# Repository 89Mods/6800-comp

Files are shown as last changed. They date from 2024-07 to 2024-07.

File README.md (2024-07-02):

# 6800-comp

Computer with a 6800 (or 6809) CPU. See [here](https://tholin.dev/6800/) for more information.

`Emu` contains an emulation of the computer (6800 mode only) written in C++.

`Hardware` contains the KiCad projects for all the boards.

`Kernal` contains the kernal sources that go on the EPROM.

`Software` contains all kinds of software I’ve written for this computer.

The [ASL Assembler](https://github.com/Macroassembler-AS/asl-releases) is required to build all code in this project.

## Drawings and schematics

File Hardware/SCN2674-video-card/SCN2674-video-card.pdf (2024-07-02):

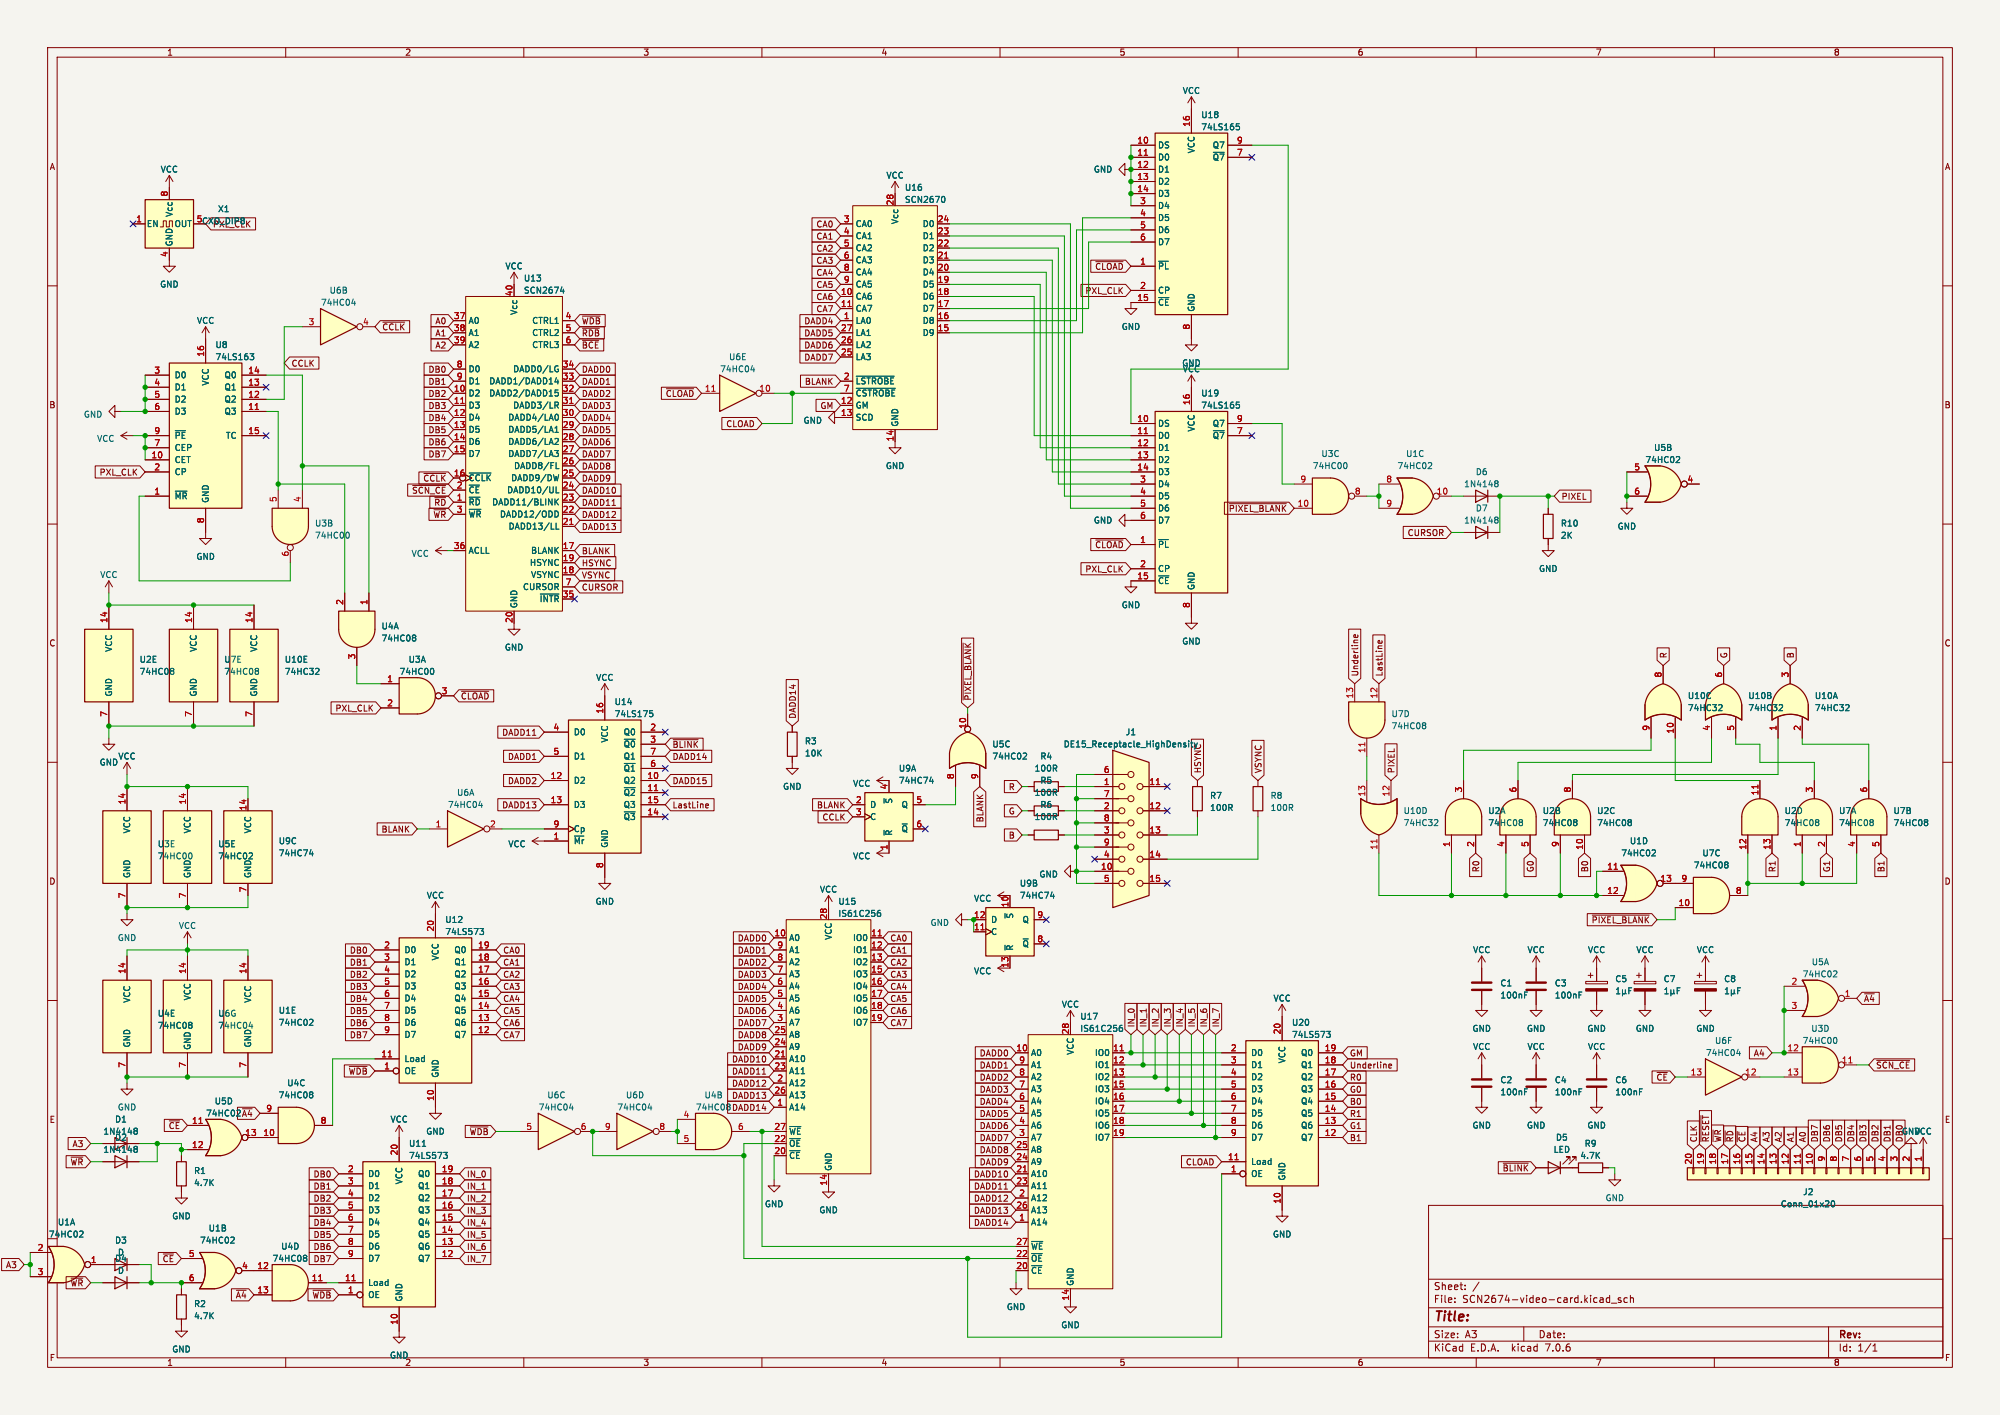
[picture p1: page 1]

VCC GND GND VCC

Id: 1/1 Title: File: SCN2674-video-card.kicad_sch Sheet: /

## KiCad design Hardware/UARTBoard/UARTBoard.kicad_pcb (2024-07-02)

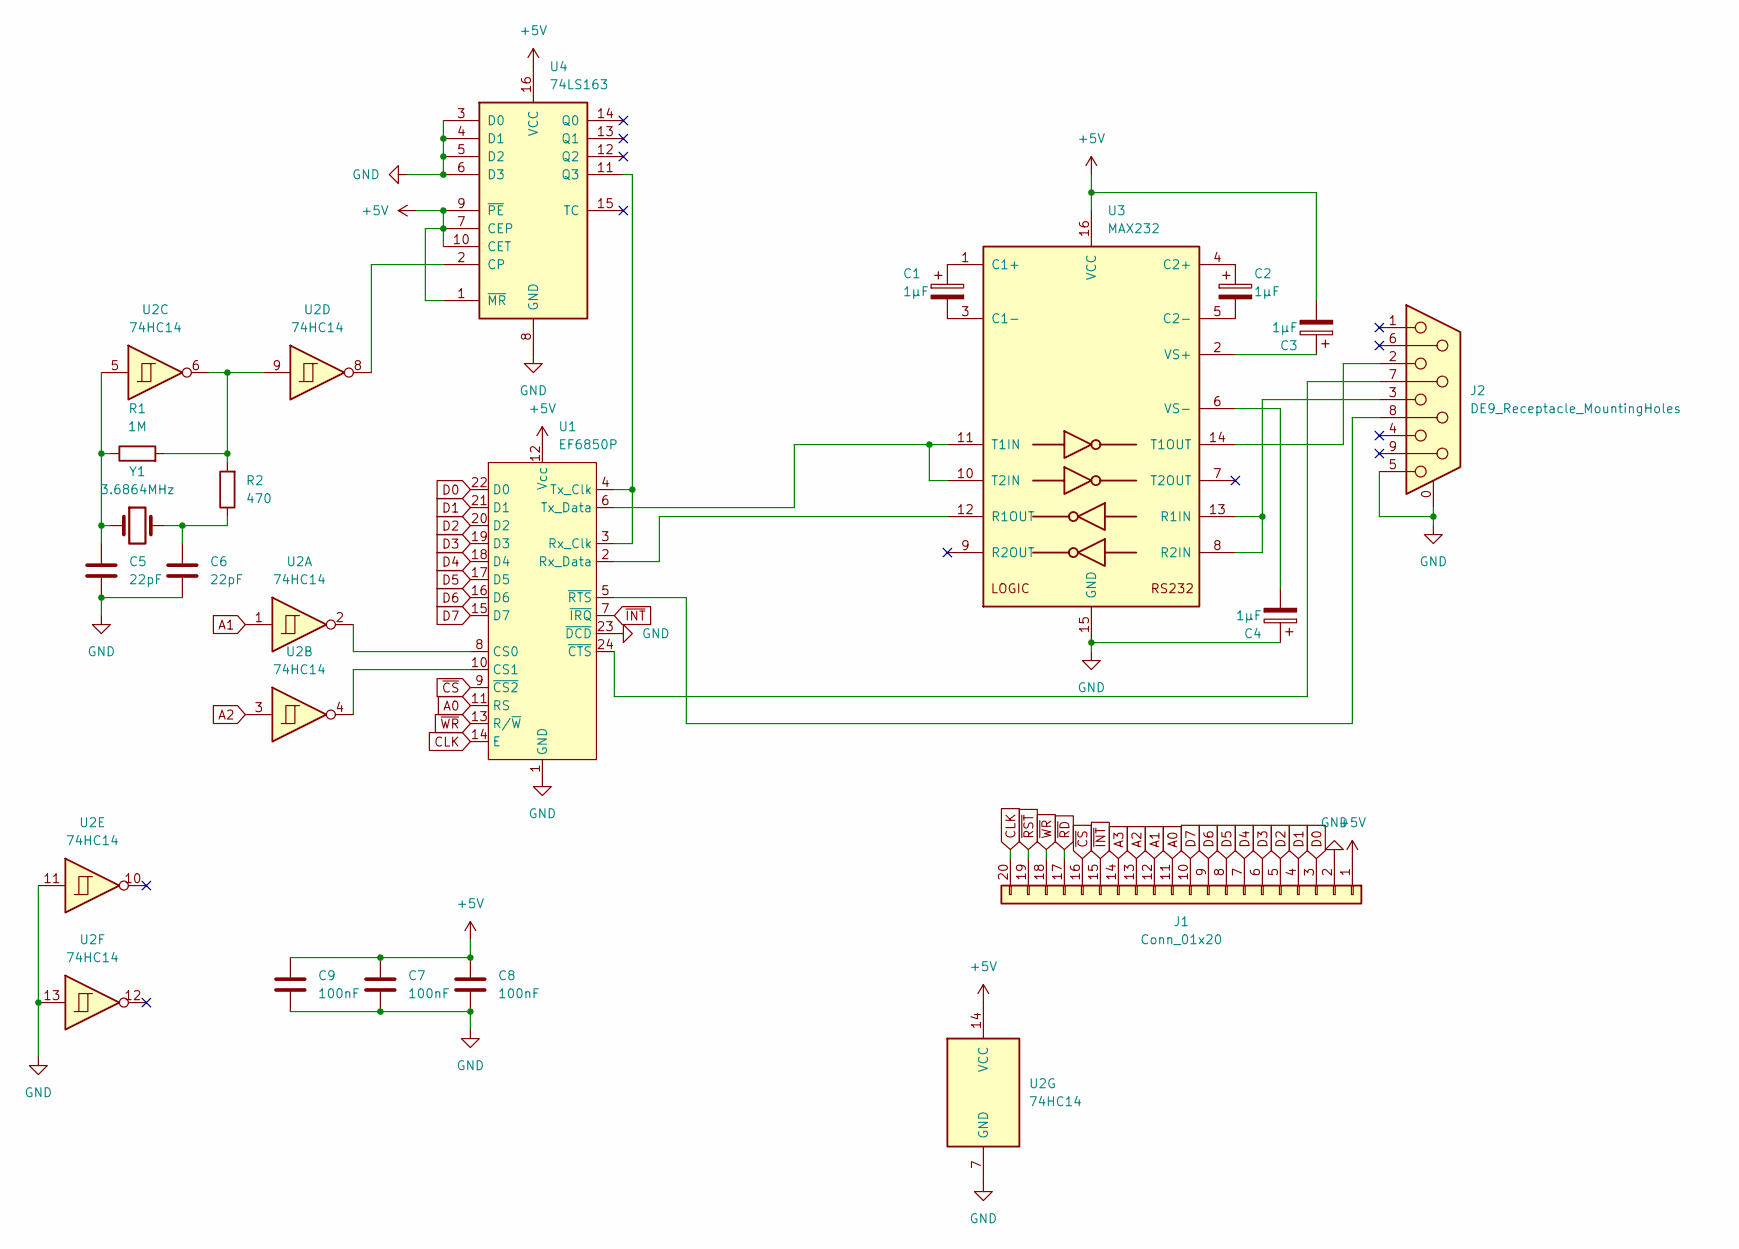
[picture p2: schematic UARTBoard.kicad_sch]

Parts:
C1, C2, C3, C4: 1µF; CP_Radial_D4.0mm_P2.00mm
C5, C6: 22pF; C_Disc_D3.0mm_W1.6mm_P2.50mm
C7, C8, C9: 100nF; C_Disc_D3.0mm_W1.6mm_P2.50mm
J1: Conn_01x20; PinHeader_1x20_P2.54mm_Vertical
J2: DE9_Receptacle_MountingHoles; DSUB-9_Female_Horizontal_P2.77x2.84mm_EdgePinOffset4.94mm_H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
R1: 1M; R_Axial_DIN0204_L3.6mm_D1.6mm_P7.62mm_Horizontal
R2: 470; R_Axial_DIN0204_L3.6mm_D1.6mm_P7.62mm_Horizontal
U1: EF6850P; DIP-24_W15.24mm
U2: 74HC14; DIP-14_W7.62mm
U3: MAX232; DIP-16_W7.62mm
U4: 74LS163; DIP-16_W7.62mm
Y1: 3.6864MHz; Crystal_HC18-U_Vertical

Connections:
+5V: C3.2, C7.1, C8.1, C9.1, J1.1, U1.12 (Vcc), U2.14 (VCC), U3.16 (VCC), U4.1 (~MR), U4.7 (CEP), U4.9 (~PE), U4.10 (CET), U4.16 (VCC)
A0: J1.11, U1.11 (RS)
A1: J1.12, U2.1
A2: J1.13, U2.3
A3: J1.14
CLK: J1.20, U1.14 (E)
D0: J1.3, U1.22 (D0)
D1: J1.4, U1.21 (D1)
D2: J1.5, U1.20 (D2)
D3: J1.6, U1.19 (D3)
D4: J1.7, U1.18 (D4)
D5: J1.8, U1.17 (D5)
D6: J1.9, U1.16 (D6)
D7: J1.10, U1.15 (D7)
GND: C4.1, C5.2, C6.2, C7.2, C8.2, C9.2, J1.2, J2.0 (PAD), J2.5, U1.1 (GND), U1.23 (~DCD), U2.7 (GND), U2.11, U2.13, U3.15 (GND), U4.3 (D0), U4.4 (D1), U4.5 (D2), U4.6 (D3), U4.8 (GND)
unnamed: C5.1, R1.1, U2.5, Y1.1
unnamed: C6.1, R2.1, Y1.2
unnamed: R1.2, R2.2, U2.6, U2.9
unnamed: U1.8 (CS0), U2.2
unnamed: U1.10 (CS1), U2.4
unnamed: U1.3 (Rx_Clk), U1.4 (Tx_Clk), U4.11 (Q3)
unnamed: U1.2 (Rx_Data), U3.12 (R1OUT)
unnamed: U1.6 (Tx_Data), U3.10 (T2IN), U3.11 (T1IN)
unnamed: J2.7, U1.24 (~CTS)
unnamed: J2.8, U1.5 (~RTS)
unnamed: C1.1, U3.1 (C1+)
unnamed: C1.2, U3.3 (C1-)
unnamed: C2.1, U3.4 (C2+)
unnamed: C2.2, U3.5 (C2-)
unnamed: J2.3, U3.8 (R2IN), U3.13 (R1IN)
unnamed: J2.2, U3.14 (T1OUT)
unnamed: C3.1, U3.2 (VS+)
unnamed: C4.2, U3.6 (VS-)
unnamed: U2.8, U4.2 (CP)
~CS: J1.16, U1.9 (~CS2)
~INT: J1.15, U1.7 (~IRQ)
~RD: J1.17
~RST: J1.19
~WR: J1.18, U1.13 (R/~W)

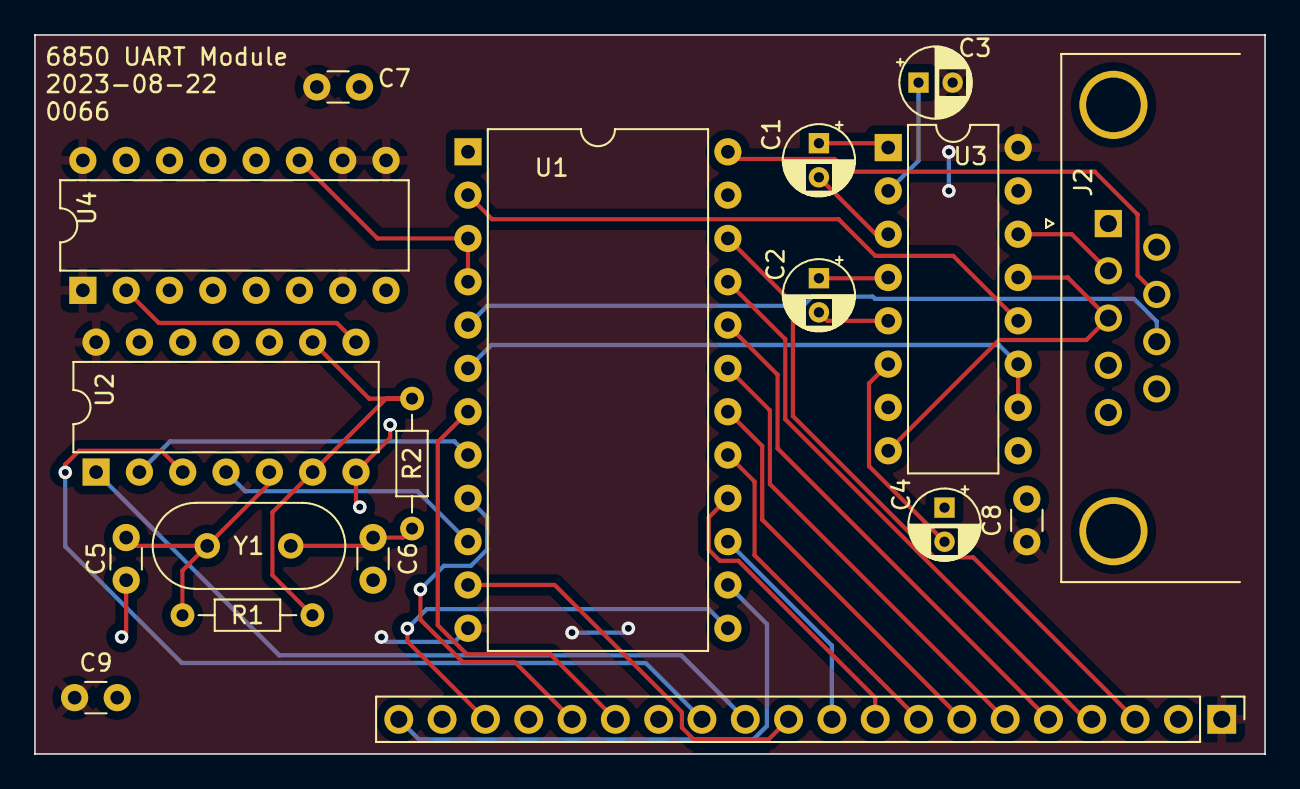
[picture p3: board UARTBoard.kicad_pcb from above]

Board: 2 copper layers, 72.1 x 42.2 mm, 18 parts (0 on the bottom side), 36 nets.

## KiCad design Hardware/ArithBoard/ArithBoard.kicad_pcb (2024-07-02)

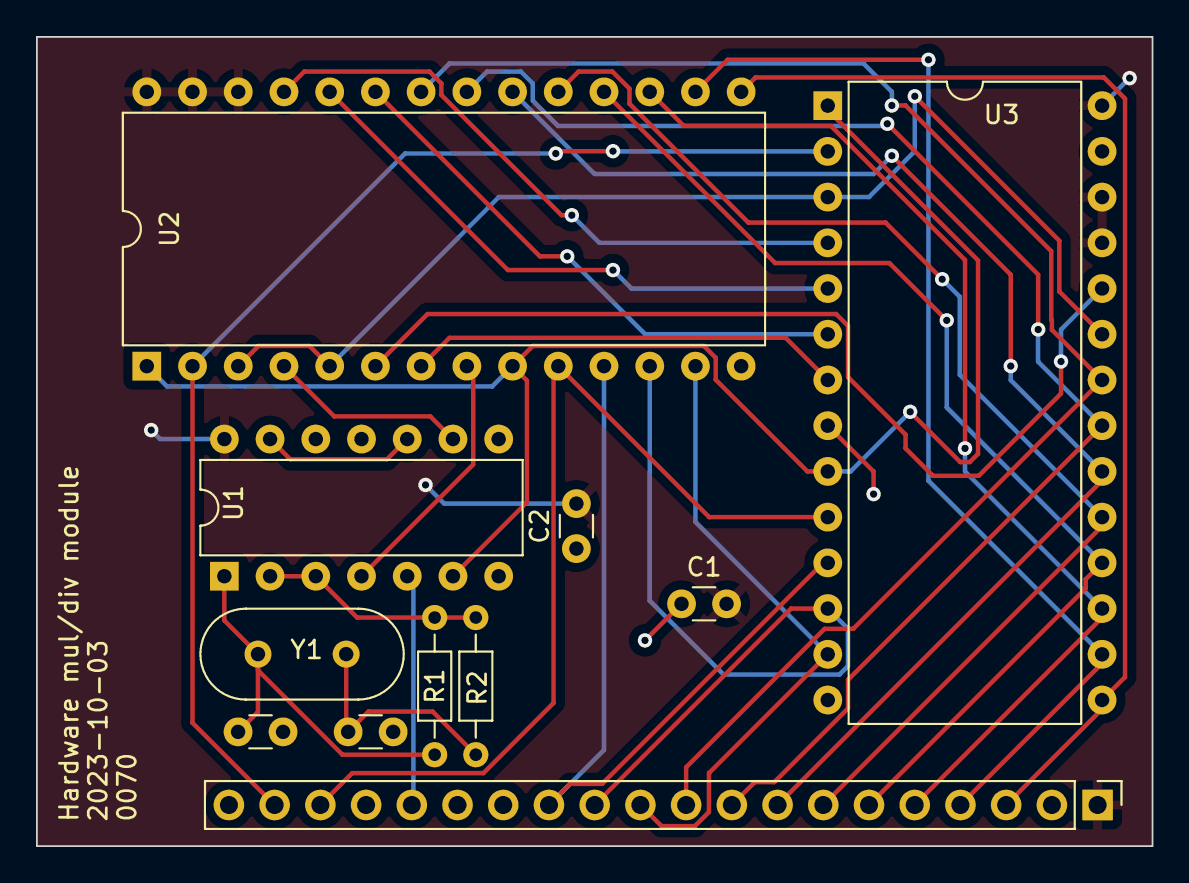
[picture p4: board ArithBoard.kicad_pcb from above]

Board: 2 copper layers, 62.0 x 45.0 mm, 11 parts (0 on the bottom side), 29 nets.

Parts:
C1, C2: 100nF; C_Disc_D3.0mm_W1.6mm_P2.50mm
C3, C4: 22pF; C_Disc_D3.0mm_W1.6mm_P2.50mm
J1: Conn_01x20; PinHeader_1x20_P2.54mm_Vertical
R1: 1M; R_Axial_DIN0204_L3.6mm_D1.6mm_P7.62mm_Horizontal
R2: 470; R_Axial_DIN0204_L3.6mm_D1.6mm_P7.62mm_Horizontal
U1: 74HC14; DIP-14_W7.62mm
U2, U3: CDP1855; DIP-28_W15.24mm
Y1: 3.6864MHz; Crystal_HC18-U_Vertical

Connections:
+5V: C1.2, C2.2, J1.1, U1.14 (VCC), U2.26 (CN1), U2.27 (CN0), U2.28 (Vdd), U3.25 (~CI), U3.26 (CN1), U3.28 (Vdd)
A0: J1.11, U2.13 (RA0), U3.13 (RA0)
A1: J1.12, U2.12 (RA1), U3.12 (RA1)
A2: J1.13, U2.11 (RA2), U3.11 (RA2)
CS: U1.6, U2.1 (CE), U2.9 (STB), U3.1 (CE), U3.9 (STB)
D0: J1.3, U2.15 (BUS0), U3.15 (BUS0)
D1: J1.4, U2.16 (BUS1), U3.16 (BUS1)
D2: J1.5, U2.17 (BUS2), U3.17 (BUS2)
D3: J1.6, U2.18 (BUS3), U3.18 (BUS3)
D4: J1.7, U2.19 (BUS4), U3.19 (BUS4)
D5: J1.8, U2.20 (BUS5), U3.20 (BUS5)
D6: J1.9, U2.21 (BUS6), U3.21 (BUS6)
D7: J1.10, U2.22 (BUS7), U3.22 (BUS7)
GND: C1.1, C2.1, C3.2, C4.2, J1.2, U1.7 (GND), U1.11, U2.14 (GND), U3.8 (CLK), U3.14 (GND), U3.27 (CN0)
unnamed: C3.1, R1.1, U1.1, Y1.1
unnamed: C4.1, R2.1, Y1.2
unnamed: R1.2, R2.2, U1.2, U1.3
unnamed: U1.10, U1.13
unnamed: U1.4, U2.8 (CLK)
unnamed: U2.3 (CTL), U2.5 (Y_L), U3.3 (CTL), U3.23 (Z_R)
unnamed: U2.24 (Y_R), U3.5 (Y_L)
unnamed: U2.6 (Z_L), U3.24 (Y_R)
unnamed: U2.23 (Z_R), U3.6 (Z_L)
unnamed: U2.25 (~CI), U3.4 (~CO/~OF)
unnamed: U1.9, U2.4 (~CO/~OF)
unnamed: U2.7 (~SHIFT), U3.7 (~SHIFT)
~CS: J1.16, U1.5
~RESET: J1.19, U2.2 (~CLEAR), U3.2 (~CLEAR)
~WR: J1.18, U2.10 (RD/~WE), U3.10 (RD/~WE)

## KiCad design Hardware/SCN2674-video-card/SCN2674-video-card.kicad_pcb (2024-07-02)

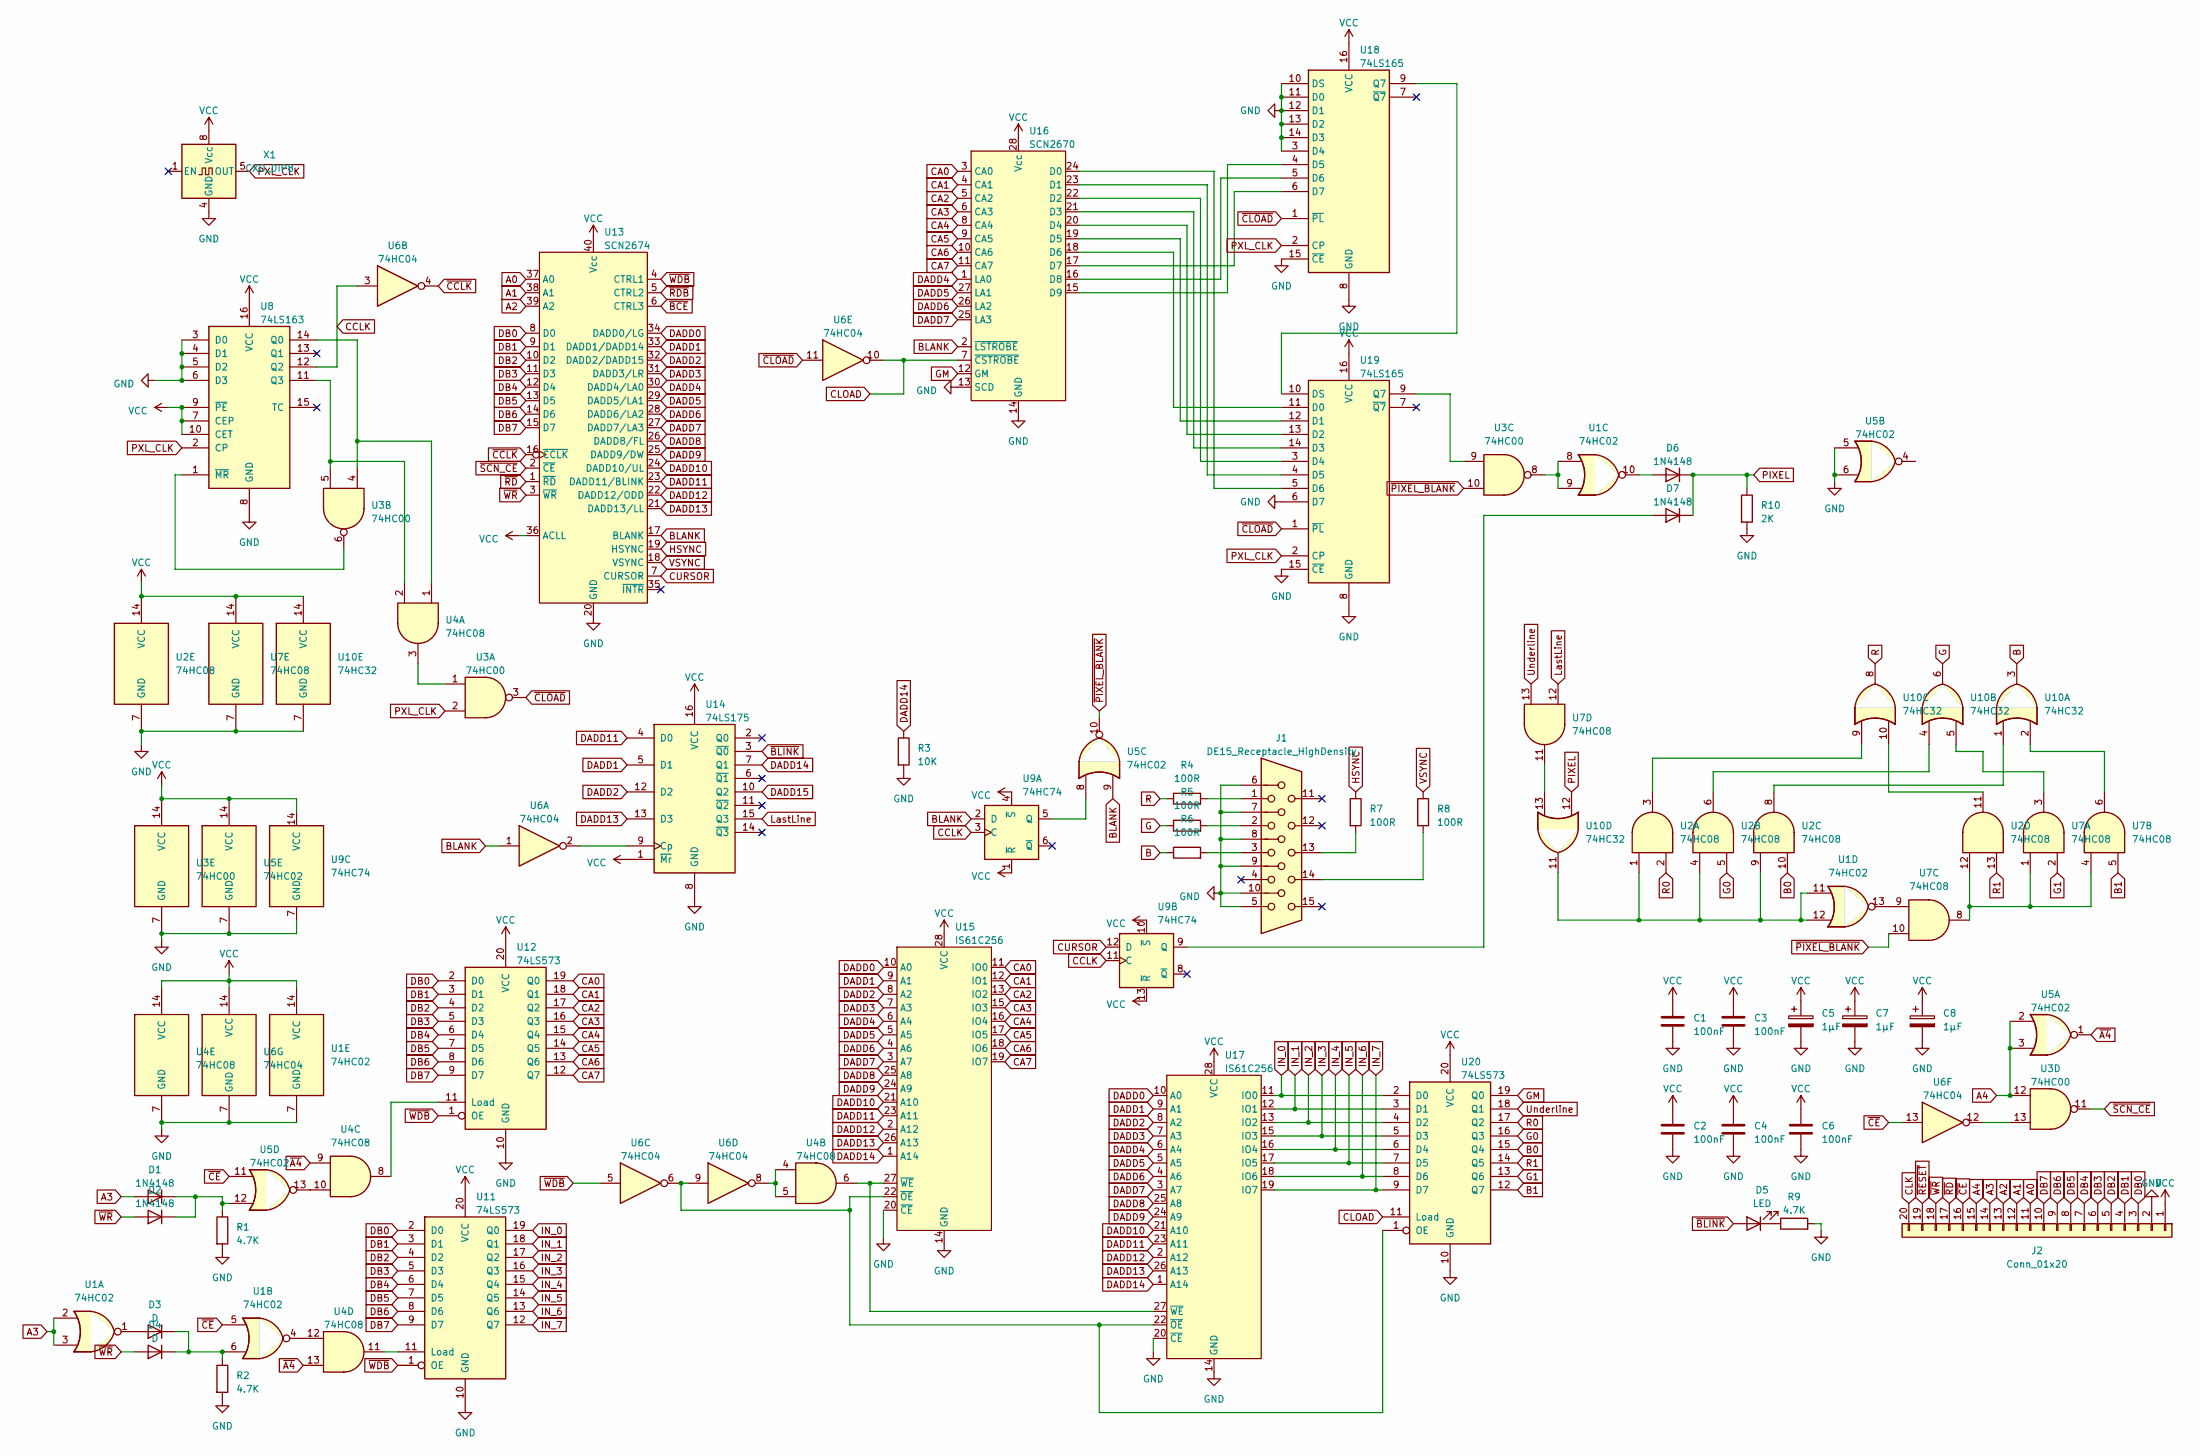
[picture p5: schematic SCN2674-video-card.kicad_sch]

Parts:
C1, C2, C3, C4, C6: 100nF; C_Axial_L5.1mm_D3.1mm_P7.50mm_Horizontal
C5, C7, C8: 1µF; CP_Radial_D4.0mm_P2.00mm
D1, D2, D6, D7: 1N4148; D_DO-34_SOD68_P7.62mm_Horizontal
D3, D4: D; D_DO-34_SOD68_P7.62mm_Horizontal
D5: LED; LED_D3.0mm
J1: DE15_Receptacle_HighDensity; DSUB-15-HD_Female_Horizontal_P2.29x1.98mm_EdgePinOffset3.03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
J2: Conn_01x20; PinHeader_1x20_P2.54mm_Vertical
R1, R2, R9: 4.7K; R_Axial_DIN0204_L3.6mm_D1.6mm_P7.62mm_Horizontal
R3: 10K; R_Axial_DIN0204_L3.6mm_D1.6mm_P7.62mm_Horizontal
R4, R5, R6, R7, R8: 100R; R_Axial_DIN0204_L3.6mm_D1.6mm_P7.62mm_Horizontal
R10: 2K; R_Axial_DIN0204_L3.6mm_D1.6mm_P7.62mm_Horizontal
U1, U5: 74HC02; DIP-14_W7.62mm
U2, U4, U7: 74HC08; DIP-14_W7.62mm
U3: 74HC00; DIP-14_W7.62mm
U6: 74HC04; DIP-14_W7.62mm
U8: 74LS163; DIP-16_W7.62mm
U9: 74HC74; DIP-14_W7.62mm
U10: 74HC32; DIP-14_W7.62mm
U11, U12, U20: 74LS573; DIP-20_W7.62mm
U13: SCN2674; DIP-40_W15.24mm
U14: 74LS175; DIP-16_W7.62mm
U15, U17: IS61C256; DIP-28_W7.62mm
U16: SCN2670; DIP-28_W15.24mm
U18, U19: 74LS165; DIP-16_W7.62mm
X1: CXO_DIP8; Oscillator_DIP-8

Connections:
A0: J2.11, U13.37 (A0)
A1: J2.12, U13.38 (A1)
A2: J2.13, U13.39 (A2)
A3: D1.2 (A), J2.14, U1.2, U1.3
A4: J2.15, U3.12, U5.2, U5.3
B: R6.1, U10.3
B0: U2.10, U20.15 (Q4)
B1: U7.5, U20.12 (Q7)
BLANK: U5.9, U6.1, U9.2 (D), U13.17 (BLANK), U16.2 (~LSTROBE)
CA0: U12.19 (Q0), U15.11 (IO0), U16.3 (CA0)
CA1: U12.18 (Q1), U15.12 (IO1), U16.4 (CA1)
CA2: U12.17 (Q2), U15.13 (IO2), U16.5 (CA2)
CA3: U12.16 (Q3), U15.15 (IO3), U16.6 (CA3)
CA4: U12.15 (Q4), U15.16 (IO4), U16.8 (CA4)
CA5: U12.14 (Q5), U15.17 (IO5), U16.9 (CA5)
CA6: U12.13 (Q6), U15.18 (IO6), U16.10 (CA6)
CA7: U12.12 (Q7), U15.19 (IO7), U16.11 (CA7)
CCLK: U6.3, U8.12 (Q2), U9.3 (C), U9.11 (C)
CLK: J2.20
CLOAD: U6.10, U16.7 (~CSTROBE), U20.11 (Load)
CURSOR: U9.12 (D), U13.7 (CURSOR)
DADD0: U13.34 (DADD0/LG), U15.10 (A0), U17.10 (A0)
DADD1: U13.33 (DADD1/DADD14), U14.5 (D1), U15.9 (A1), U17.9 (A1)
DADD2: U13.32 (DADD2/DADD15), U14.12 (D2), U15.8 (A2), U17.8 (A2)
DADD3: U13.31 (DADD3/LR), U15.7 (A3), U17.7 (A3)
DADD4: U13.30 (DADD4/LA0), U15.6 (A4), U16.1 (LA0), U17.6 (A4)
DADD5: U13.29 (DADD5/LA1), U15.5 (A5), U16.27 (LA1), U17.5 (A5)
DADD6: U13.28 (DADD6/LA2), U15.4 (A6), U16.26 (LA2), U17.4 (A6)
DADD7: U13.27 (DADD7/LA3), U15.3 (A7), U16.25 (LA3), U17.3 (A7)
DADD8: U13.26 (DADD8/FL), U15.25 (A8), U17.25 (A8)
DADD9: U13.25 (DADD9/DW), U15.24 (A9), U17.24 (A9)
DADD10: U13.24 (DADD10/UL), U15.21 (A10), U17.21 (A10)
DADD11: U13.23 (DADD11/BLINK), U14.4 (D0), U15.23 (A11), U17.23 (A11)
DADD12: U13.22 (DADD12/ODD), U15.2 (A12), U17.2 (A12)
DADD13: U13.21 (DADD13/LL), U14.13 (D3), U15.26 (A13), U17.26 (A13)
DADD14: R3.1, U14.7 (Q1), U15.1 (A14), U17.1 (A14)
DADD15: U14.10 (Q2)
DB0: J2.3, U11.2 (D0), U12.2 (D0), U13.8 (D0)
DB1: J2.4, U11.3 (D1), U12.3 (D1), U13.9 (D1)
DB2: J2.5, U11.4 (D2), U12.4 (D2), U13.10 (D2)
DB3: J2.6, U11.5 (D3), U12.5 (D3), U13.11 (D3)
DB4: J2.7, U11.6 (D4), U12.6 (D4), U13.12 (D4)
DB5: J2.8, U11.7 (D5), U12.7 (D5), U13.13 (D5)
DB6: J2.9, U11.8 (D6), U12.8 (D6), U13.14 (D6)
DB7: J2.10, U11.9 (D7), U12.9 (D7), U13.15 (D7)
G: R5.1, U10.6
G0: U2.5, U20.16 (Q3)
G1: U7.2, U20.13 (Q6)
GM: U16.12 (GM), U20.19 (Q0)
GND: C1.2, C2.2, C3.2, C4.2, C5.2, C6.2, C7.2, C8.2, J1.5, J1.6, J1.7, J1.8, J1.9, J1.10, J2.2, R1.2, R2.2, R3.2, R9.2, R10.2, U1.7 (GND), U2.7 (GND), U3.7 (GND), U4.7 (GND), U5.5, U5.6, U5.7 (GND), U6.7 (GND), U7.7 (GND), U8.3 (D0), U8.4 (D1), U8.5 (D2), U8.6 (D3), U8.8 (GND), U9.7 (GND), U10.7 (GND), U11.10 (GND), U12.10 (GND), U13.20 (GND), U14.8 (GND), U15.14 (GND), U15.20 (~CE), U16.13 (SCD), U16.14 (GND), U17.14 (GND), U17.20 (~CE), U18.3 (D4), U18.8 (GND), U18.10 (DS), U18.11 (D0), U18.12 (D1), U18.13 (D2), U18.14 (D3), U18.15 (~CE), U19.6 (D7), U19.8 (GND), U19.15 (~CE), U20.10 (GND), X1.4 (GND)
HSYNC: R7.1, U13.19 (HSYNC)
IN_0: U11.19 (Q0), U17.11 (IO0), U20.2 (D0)
IN_1: U11.18 (Q1), U17.12 (IO1), U20.3 (D1)
IN_2: U11.17 (Q2), U17.13 (IO2), U20.4 (D2)
IN_3: U11.16 (Q3), U17.15 (IO3), U20.5 (D3)
IN_4: U11.15 (Q4), U17.16 (IO4), U20.6 (D4)
IN_5: U11.14 (Q5), U17.17 (IO5), U20.7 (D5)
IN_6: U11.13 (Q6), U17.18 (IO6), U20.8 (D6)
IN_7: U11.12 (Q7), U17.19 (IO7), U20.9 (D7)
LastLine: U7.12, U14.15 (Q3)
unnamed: D1.1 (K), D2.1 (K), R1.1, U5.12
unnamed: D3.2 (A), U1.1
unnamed: D3.1 (K), D4.1 (K), R2.1, U1.6
unnamed: D5.1 (K), R9.1
unnamed: D6.2 (A), U1.10
unnamed: D7.2 (A), U9.9 (Q)
unnamed: J1.1, R4.2
unnamed: J1.2, R5.2
unnamed: J1.3, R6.2
unnamed: J1.13, R7.2
unnamed: J1.14, R8.2
unnamed: U1.4, U4.12
unnamed: U1.8, U1.9, U3.8
unnamed: U1.11, U1.12, U2.1, U2.4, U2.9, U10.11
unnamed: U1.13, U7.9
unnamed: U2.12, U7.1, U7.4, U7.8
unnamed: U3.1, U4.3
unnamed: U3.13, U6.12
unnamed: U4.4, U4.5, U6.8
unnamed: U4.10, U5.13
unnamed: U3.4, U4.1, U8.14 (Q0)
unnamed: U3.5, U4.2, U8.11 (Q3)
unnamed: U3.6, U8.1 (~MR)
unnamed: U5.8, U9.5 (Q)
unnamed: U2.8, U10.1
unnamed: U7.6, U10.2
unnamed: U2.6, U10.4
unnamed: U7.3, U10.5
unnamed: U2.3, U10.9
unnamed: U2.11, U10.10
unnamed: U7.11, U10.13
unnamed: U4.11, U11.11 (Load)
unnamed: U4.8, U12.11 (Load)
unnamed: U6.2, U14.9 (Cp)
unnamed: U6.6, U6.9, U15.22 (~OE), U17.22 (~OE), U20.1 (OE)
unnamed: U4.6, U15.27 (~WE), U17.27 (~WE)
unnamed: U16.24 (D0), U19.5 (D6)
unnamed: U16.23 (D1), U19.4 (D5)
unnamed: U16.22 (D2), U19.3 (D4)
unnamed: U16.21 (D3), U19.14 (D3)
unnamed: U16.20 (D4), U19.13 (D2)
unnamed: U16.19 (D5), U19.12 (D1)
unnamed: U16.18 (D6), U19.11 (D0)
unnamed: U16.17 (D7), U18.6 (D7)
unnamed: U16.16 (D8), U18.5 (D6)
unnamed: U16.15 (D9), U18.4 (D5)
unnamed: U18.9 (Q7), U19.10 (DS)
unnamed: U3.9, U19.9 (Q7)
PIXEL: D6.1 (K), D7.1 (K), R10.1, U10.12
PXL_CLK: U3.2, U8.2 (CP), U18.2 (CP), U19.2 (CP), X1.5 (OUT)
R: R4.1, U10.8
R0: U2.2, U20.17 (Q2)
R1: U2.13, U20.14 (Q5)
Underline: U7.13, U20.18 (Q1)
VCC: C1.1, C2.1, C3.1, C4.1, C5.1, C6.1, C7.1, C8.1, J2.1, U1.14 (VCC), U2.14 (VCC), U3.14 (VCC), U4.14 (VCC), U5.14 (VCC), U6.14 (VCC), U7.14 (VCC), U8.7 (CEP), U8.9 (~PE), U8.10 (CET), U8.16 (VCC), U9.1 (~R), U9.4 (~S), U9.10 (~S), U9.13 (~R), U9.14 (VCC), U10.14 (VCC), U11.20 (VCC), U12.20 (VCC), U13.36 (ACLL), U13.40 (Vcc), U14.1 (~Mr), U14.16 (VCC), U15.28 (VCC), U16.28 (Vcc), U17.28 (VCC), U18.16 (VCC), U19.16 (VCC), U20.20 (VCC), X1.8 (Vcc)
VSYNC: R8.1, U13.18 (VSYNC)
~A4: U4.9, U4.13, U5.1
~BCE: U13.6 (CTRL3)
~BLINK: D5.2 (A), U14.3 (~Q0)
~CCLK: U6.4, U13.16 (~CCLK)
~CE: J2.16, U1.5, U5.11, U6.13
~CLOAD: U3.3, U6.11, U18.1 (~PL), U19.1 (~PL)
~PIXEL_BLANK: U3.10, U5.10, U7.10
~RDB: U13.5 (CTRL2)
~RD: J2.17, U13.1 (~RD)
~RESET: J2.19
~SCN_CE: U3.11, U13.2 (~CE)
~WDB: U6.5, U11.1 (OE), U12.1 (OE), U13.4 (CTRL1)
~WR: D2.2 (A), D4.2 (A), J2.18, U13.3 (~WR)

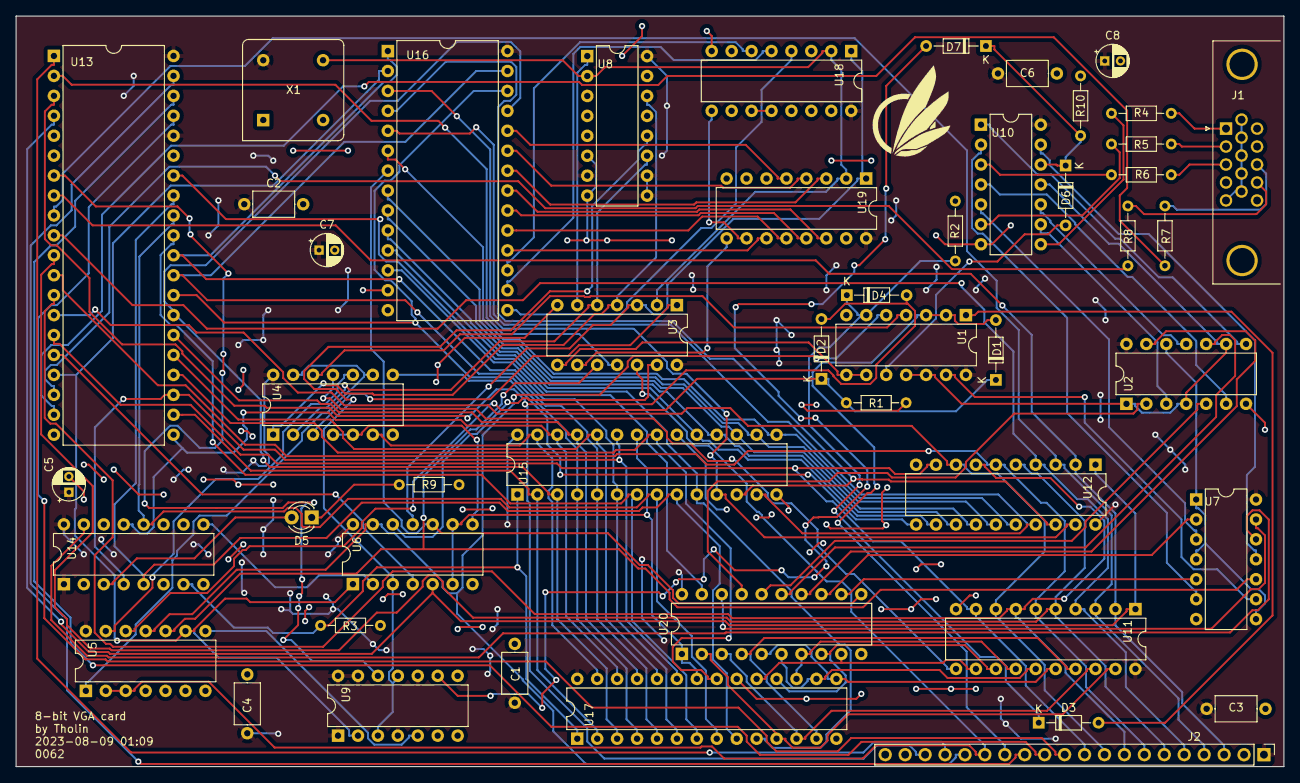
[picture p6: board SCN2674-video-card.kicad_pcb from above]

Board: 2 copper layers, 161.5 x 95.6 mm, 48 parts (0 on the bottom side), 124 nets.

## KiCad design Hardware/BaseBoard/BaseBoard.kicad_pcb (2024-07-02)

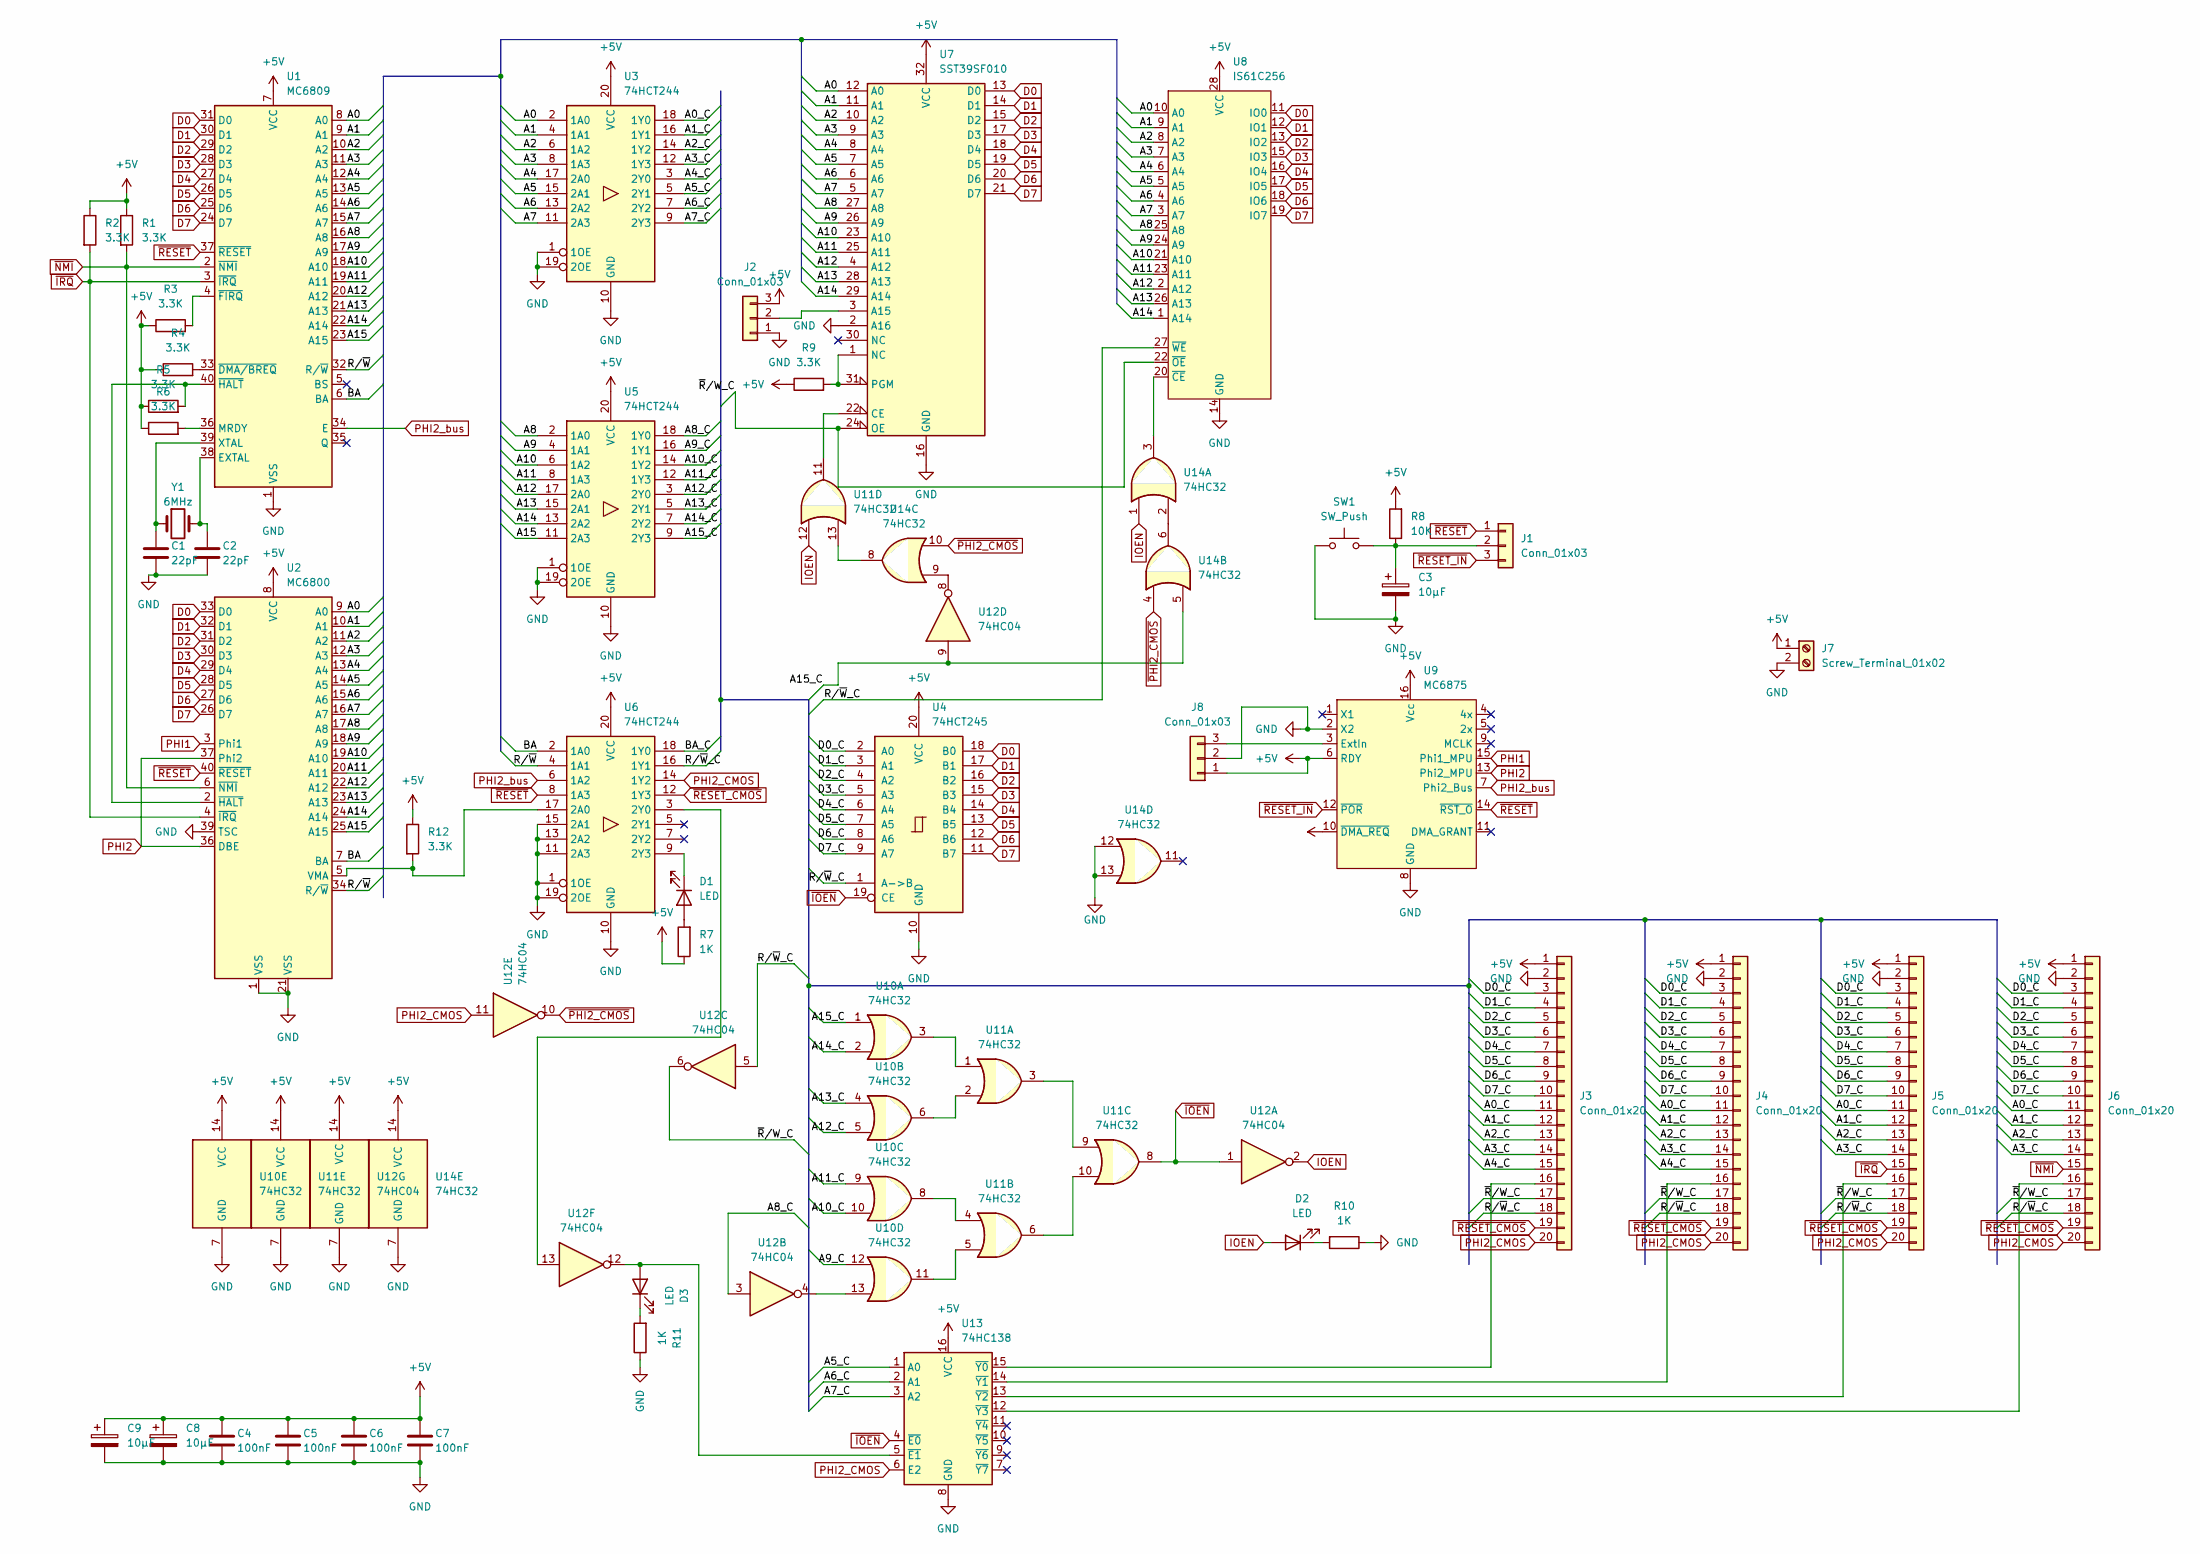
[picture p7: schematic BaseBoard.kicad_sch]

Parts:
C1, C2: 22pF; C_Disc_D3.0mm_W1.6mm_P2.50mm
C3, C8, C9: 10µF; CP_Radial_D4.0mm_P2.00mm
C4, C5, C6, C7: 100nF; C_Disc_D3.0mm_W1.6mm_P2.50mm
D1: LED; LED_D3.0mm
D2, D3: LED; LED_1206_3216Metric_Pad1.42x1.75mm_HandSolder
J1, J2, J8: Conn_01x03; PinHeader_1x03_P2.54mm_Vertical
J3, J4, J5, J6: Conn_01x20; PinSocket_1x20_P2.54mm_Vertical
J7: Screw_Terminal_01x02; TerminalBlock_bornier-2_P5.08mm
R1, R2, R3, R4, R5, R6, R9, R12: 3.3K; R_Axial_DIN0204_L3.6mm_D1.6mm_P7.62mm_Horizontal
R7: 1K; R_Axial_DIN0204_L3.6mm_D1.6mm_P7.62mm_Horizontal
R8: 10K; R_Axial_DIN0204_L3.6mm_D1.6mm_P7.62mm_Horizontal
R10, R11: 1K; R_1206_3216Metric_Pad1.30x1.75mm_HandSolder
SW1: SW_Push; SW_PUSH_6mm
U1: MC6809; DIP-40_W15.24mm
U2: MC6800; DIP-40_W15.24mm
U3, U5, U6: 74HCT244; DIP-20_W7.62mm
U4: 74HCT245; DIP-20_W7.62mm
U7: SST39SF010; DIP-32_W15.24mm
U8: IS61C256; DIP-28_W7.62mm
U9: MC6875; DIP-16_W7.62mm
U10, U11, U14: 74HC32; DIP-14_W7.62mm
U12: 74HC04; DIP-14_W7.62mm
U13: 74HC138; DIP-16_W7.62mm
Y1: 6MHz; Crystal_HC18-U_Vertical

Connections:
+5V: C4.1, C5.1, C6.1, C7.1, C8.1, C9.1, J2.3, J3.1, J4.1, J5.1, J6.1, J7.1, J8.1, R1.1, R2.1, R3.1, R4.1, R5.1, R6.1, R7.1, R8.2, R9.1, R12.1, U1.7 (VCC), U2.8 (VCC), U3.20 (VCC), U4.20 (VCC), U5.20 (VCC), U6.20 (VCC), U7.32 (VCC), U8.28 (VCC), U9.6 (RDY), U9.10 (~DMA_REQ), U9.16 (Vcc), U10.14 (VCC), U11.14 (VCC), U12.14 (VCC), U13.16 (VCC), U14.14 (VCC)
/A0: U1.8 (A0), U2.9 (A0), U3.2 (1A0), U7.12 (A0), U8.10 (A0)
/A0_C: J3.11, J4.11, J5.11, J6.11, U3.18 (1Y0)
/A1: U1.9 (A1), U2.10 (A1), U3.4 (1A1), U7.11 (A1), U8.9 (A1)
/A1_C: J3.12, J4.12, J5.12, J6.12, U3.16 (1Y1)
/A2: U1.10 (A2), U2.11 (A2), U3.6 (1A2), U7.10 (A2), U8.8 (A2)
/A2_C: J3.13, J4.13, J5.13, J6.13, U3.14 (1Y2)
/A3: U1.11 (A3), U2.12 (A3), U3.8 (1A3), U7.9 (A3), U8.7 (A3)
/A3_C: J3.14, J4.14, J5.14, J6.14, U3.12 (1Y3)
/A4: U1.12 (A4), U2.13 (A4), U3.17 (2A0), U7.8 (A4), U8.6 (A4)
/A4_C: J3.15, J4.15, U3.3 (2Y0)
/A5: U1.13 (A5), U2.14 (A5), U3.15 (2A1), U7.7 (A5), U8.5 (A5)
/A5_C: U3.5 (2Y1), U13.1 (A0)
/A6: U1.14 (A6), U2.15 (A6), U3.13 (2A2), U7.6 (A6), U8.4 (A6)
/A6_C: U3.7 (2Y2), U13.2 (A1)
/A7: U1.15 (A7), U2.16 (A7), U3.11 (2A3), U7.5 (A7), U8.3 (A7)
/A7_C: U3.9 (2Y3), U13.3 (A2)
/A8: U1.16 (A8), U2.17 (A8), U5.2 (1A0), U7.27 (A8), U8.25 (A8)
/A8_C: U5.18 (1Y0), U12.3
/A9: U1.17 (A9), U2.18 (A9), U5.4 (1A1), U7.26 (A9), U8.24 (A9)
/A9_C: U5.16 (1Y1), U10.12
/A10: U1.18 (A10), U2.19 (A10), U5.6 (1A2), U7.23 (A10), U8.21 (A10)
/A10_C: U5.14 (1Y2), U10.10
/A11: U1.19 (A11), U2.20 (A11), U5.8 (1A3), U7.25 (A11), U8.23 (A11)
/A11_C: U5.12 (1Y3), U10.9
/A12: U1.20 (A12), U2.22 (A12), U5.17 (2A0), U7.4 (A12), U8.2 (A12)
/A12_C: U5.3 (2Y0), U10.5
/A13: U1.21 (A13), U2.23 (A13), U5.15 (2A1), U7.28 (A13), U8.26 (A13)
/A13_C: U5.5 (2Y1), U10.4
/A14: U1.22 (A14), U2.24 (A14), U5.13 (2A2), U7.29 (A14), U8.1 (A14)
/A14_C: U5.7 (2Y2), U10.2
/A15: U1.23 (A15), U2.25 (A15), U5.11 (2A3)
/A15_C: U5.9 (2Y3), U10.1, U12.9, U14.5
/BA: U1.6 (BA), U2.7 (BA), U6.2 (1A0)
/BA_C: U6.18 (1Y0)
/D0_C: J3.3, J4.3, J5.3, J6.3, U4.2 (A0)
/D1_C: J3.4, J4.4, J5.4, J6.4, U4.3 (A1)
/D2_C: J3.5, J4.5, J5.5, J6.5, U4.4 (A2)
/D3_C: J3.6, J4.6, J5.6, J6.6, U4.5 (A3)
/D4_C: J3.7, J4.7, J5.7, J6.7, U4.6 (A4)
/D5_C: J3.8, J4.8, J5.8, J6.8, U4.7 (A5)
/D6_C: J3.9, J4.9, J5.9, J6.9, U4.8 (A6)
/D7_C: J3.10, J4.10, J5.10, J6.10, U4.9 (A7)
/R/~W: U1.32 (R/~W), U2.34 (R/~W), U6.4 (1A1)
/R/~W_C: J3.18, J4.18, J5.18, J6.18, U4.1 (A->B), U6.16 (1Y1), U8.27 (~WE), U12.5
/~R/W_C: J3.17, J4.17, J5.17, J6.17, U7.24 (OE), U8.22 (~OE), U12.6
D0: U1.31 (D0), U2.33 (D0), U4.18 (B0), U7.13 (D0), U8.11 (IO0)
D1: U1.30 (D1), U2.32 (D1), U4.17 (B1), U7.14 (D1), U8.12 (IO1)
D2: U1.29 (D2), U2.31 (D2), U4.16 (B2), U7.15 (D2), U8.13 (IO2)
D3: U1.28 (D3), U2.30 (D3), U4.15 (B3), U7.17 (D3), U8.15 (IO3)
D4: U1.27 (D4), U2.29 (D4), U4.14 (B4), U7.18 (D4), U8.16 (IO4)
D5: U1.26 (D5), U2.28 (D5), U4.13 (B5), U7.19 (D5), U8.17 (IO5)
D6: U1.25 (D6), U2.27 (D6), U4.12 (B6), U7.20 (D6), U8.18 (IO6)
D7: U1.24 (D7), U2.26 (D7), U4.11 (B7), U7.21 (D7), U8.19 (IO7)
IOEN: D2.2 (A), U11.12, U12.2, U14.1
unnamed: D1.2 (A), R7.2
unnamed: D1.1 (K), U6.9 (2Y3)
unnamed: D2.1 (K), R10.2
unnamed: D3.1 (K), R11.2
unnamed: C3.1, J1.2, R8.1, SW1.2
unnamed: J2.2, U7.3 (A15)
unnamed: J3.16, U13.15 (~Y0)
unnamed: J4.16, U13.14 (~Y1)
unnamed: J5.16, U13.13 (~Y2)
unnamed: J6.16, U13.12 (~Y3)
unnamed: J8.3, U9.3 (ExtIn)
unnamed: C2.1, U1.38 (EXTAL), Y1.2
unnamed: R6.2, U1.36 (MRDY)
unnamed: C1.1, U1.39 (XTAL), Y1.1
unnamed: R4.2, U1.33 (~DMA/BREQ)
unnamed: R3.2, U1.4 (~FIRQ)
unnamed: R5.2, U1.40 (~HALT), U2.2 (~HALT)
unnamed: U7.22 (CE), U11.11
unnamed: R9.2, U7.1 (NC), U7.31 (PGM)
unnamed: U8.20 (~CE), U14.3
unnamed: U10.3, U11.1
unnamed: U10.6, U11.2
unnamed: U10.8, U11.4
unnamed: U10.11, U11.5
unnamed: U10.13, U12.4
unnamed: U11.3, U11.9
unnamed: U11.6, U11.10
unnamed: U11.13, U14.8
unnamed: U12.8, U14.9
unnamed: U14.2, U14.6
PHI1: U2.3 (Phi1), U9.15 (Phi1_MPU)
PHI2: U2.36 (DBE), U2.37 (Phi2), U9.13 (Phi2_MPU)
PHI2_CMOS: J3.20, J4.20, J5.20, J6.20, U6.14 (1Y2), U12.11, U13.6 (E2)
PHI2_bus: U1.34 (E), U6.6 (1A2), U9.7 (Phi2_Bus)
~IOEN: U4.19 (CE), U11.8, U12.1, U13.4 (~E0)
~IRQ: J5.15, R2.2, U1.3 (~IRQ), U2.4 (~IRQ)
~NMI: J6.15, R1.2, U1.2 (~NMI), U2.6 (~NMI)
~PHI2_CMOS: U12.10, U14.4, U14.10
~RESET_CMOS: J3.19, J4.19, J5.19, J6.19, U6.12 (1Y3)
~RESET_IN: J1.3, U9.12 (~POR)
~RESET: J1.1, U1.37 (~RESET), U2.40 (~RESET), U6.8 (1A3), U9.14 (~RST_O)

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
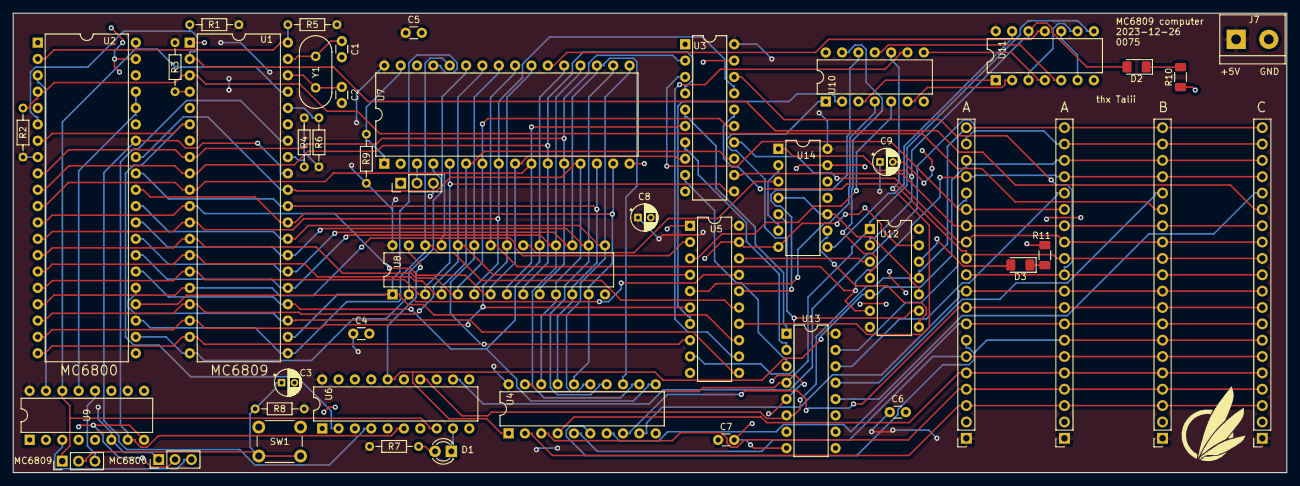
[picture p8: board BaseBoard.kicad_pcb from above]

Board: 2 copper layers, 197.9 x 71.4 mm, 47 parts (0 on the bottom side), 97 nets.

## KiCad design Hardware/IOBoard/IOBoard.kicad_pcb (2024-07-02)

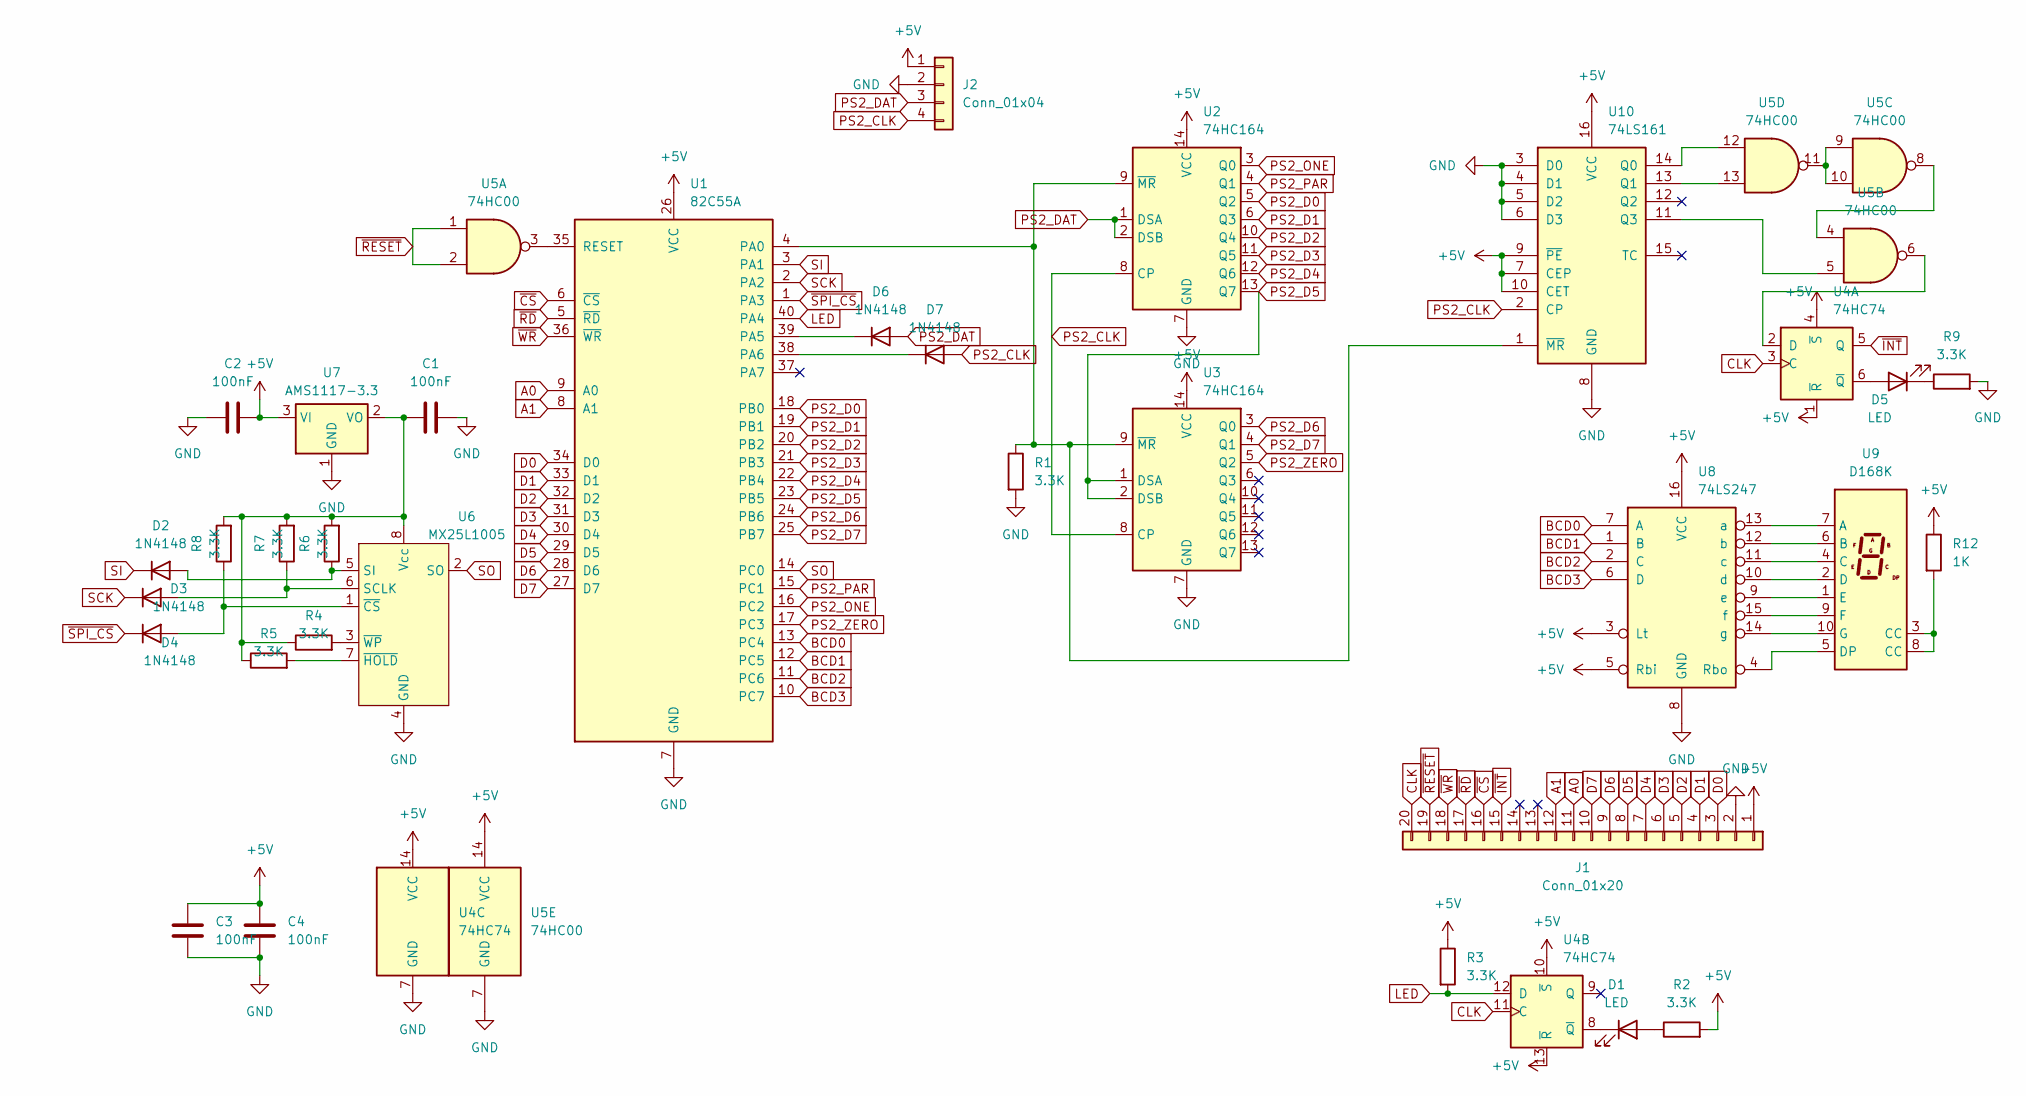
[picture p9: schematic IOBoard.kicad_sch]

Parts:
C1, C2, C3, C4: 100nF; C_Disc_D3.0mm_W1.6mm_P2.50mm
D1, D5: LED; LED_D3.0mm
D2, D3, D4, D6, D7: 1N4148; D_DO-34_SOD68_P7.62mm_Horizontal
J1: Conn_01x20; PinHeader_1x20_P2.54mm_Vertical
J2: Conn_01x04; PinHeader_1x04_P2.54mm_Vertical
R1, R2, R3, R4, R5, R6, R7, R8, R9: 3.3K; R_Axial_DIN0204_L3.6mm_D1.6mm_P7.62mm_Horizontal
R12: 1K; R_Axial_DIN0204_L3.6mm_D1.6mm_P7.62mm_Horizontal
U1: 82C55A; DIP-40_W15.24mm
U2, U3: 74HC164; DIP-14_W7.62mm
U4: 74HC74; DIP-14_W7.62mm
U5: 74HC00; DIP-14_W7.62mm
U6: MX25L1005; DIP-8_W7.62mm
U7: AMS1117-3.3; SOT-223-3_TabPin2
U8: 74LS247; DIP-16_W7.62mm
U9: D168K; D1X8K
U10: 74LS161; DIP-16_W7.62mm

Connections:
+5V: C2.2, C3.2, C4.2, J1.1, J2.1, R2.2, R3.1, R12.1, U1.26 (VCC), U2.14 (VCC), U3.14 (VCC), U4.1 (~R), U4.4 (~S), U4.10 (~S), U4.13 (~R), U4.14 (VCC), U5.14 (VCC), U7.3 (VI), U8.3 (Lt), U8.5 (Rbi), U8.16 (VCC), U10.7 (CEP), U10.9 (~PE), U10.10 (CET), U10.16 (VCC)
A0: J1.11, U1.9 (A0)
A1: J1.12, U1.8 (A1)
BCD0: U1.13 (PC4), U8.7 (A)
BCD1: U1.12 (PC5), U8.1 (B)
BCD2: U1.11 (PC6), U8.2 (C)
BCD3: U1.10 (PC7), U8.6 (D)
CLK: J1.20, U4.3 (C), U4.11 (C)
D0: J1.3, U1.34 (D0)
D1: J1.4, U1.33 (D1)
D2: J1.5, U1.32 (D2)
D3: J1.6, U1.31 (D3)
D4: J1.7, U1.30 (D4)
D5: J1.8, U1.29 (D5)
D6: J1.9, U1.28 (D6)
D7: J1.10, U1.27 (D7)
GND: C1.2, C2.1, C3.1, C4.1, J1.2, J2.2, R1.2, R9.2, U1.7 (GND), U2.7 (GND), U3.7 (GND), U4.7 (GND), U5.7 (GND), U6.4 (GND), U7.1 (GND), U8.8 (GND), U10.3 (D0), U10.4 (D1), U10.5 (D2), U10.6 (D3), U10.8 (GND)
LED: R3.2, U1.40 (PA4), U4.12 (D)
unnamed: D1.2 (A), R2.1
unnamed: D1.1 (K), U4.8 (~Q)
unnamed: D2.2 (A), R6.1, U6.5 (SI)
unnamed: D3.2 (A), R7.1, U6.6 (SCLK)
unnamed: D4.2 (A), R8.1, U6.1 (~CS)
unnamed: D5.2 (A), U4.6 (~Q)
unnamed: D5.1 (K), R9.1
unnamed: D6.1 (K), U1.39 (PA5)
unnamed: D7.1 (K), U1.38 (PA6)
unnamed: R12.2, U9.3 (CC), U9.8 (CC)
unnamed: R1.1, U1.4 (PA0), U2.9 (~MR), U3.9 (~MR), U10.1 (~MR)
unnamed: U1.35 (RESET), U5.3
unnamed: U4.2 (D), U5.6
unnamed: U5.4, U5.8
unnamed: U5.9, U5.10, U5.11
unnamed: C1.1, R4.1, R5.1, R6.2, R7.2, R8.2, U6.8 (Vcc), U7.2 (VO)
unnamed: R5.2, U6.7 (~HOLD)
unnamed: R4.2, U6.3 (~WP)
unnamed: U8.4 (Rbo), U9.5 (DP)
unnamed: U8.13 (a), U9.7 (A)
unnamed: U8.12 (b), U9.6 (B)
unnamed: U8.11 (c), U9.4 (C)
unnamed: U8.10 (d), U9.2 (D)
unnamed: U8.9 (e), U9.1 (E)
unnamed: U8.15 (f), U9.9 (F)
unnamed: U8.14 (g), U9.10 (G)
unnamed: U5.12, U10.14 (Q0)
unnamed: U5.13, U10.13 (Q1)
unnamed: U5.5, U10.11 (Q3)
PS2_CLK: D7.2 (A), J2.4, U2.8 (CP), U3.8 (CP), U10.2 (CP)
PS2_D0: U1.18 (PB0), U2.5 (Q2)
PS2_D1: U1.19 (PB1), U2.6 (Q3)
PS2_D2: U1.20 (PB2), U2.10 (Q4)
PS2_D3: U1.21 (PB3), U2.11 (Q5)
PS2_D4: U1.22 (PB4), U2.12 (Q6)
PS2_D5: U1.23 (PB5), U2.13 (Q7), U3.1 (DSA), U3.2 (DSB)
PS2_D6: U1.24 (PB6), U3.3 (Q0)
PS2_D7: U1.25 (PB7), U3.4 (Q1)
PS2_DAT: D6.2 (A), J2.3, U2.1 (DSA), U2.2 (DSB)
PS2_ONE: U1.16 (PC2), U2.3 (Q0)
PS2_PAR: U1.15 (PC1), U2.4 (Q1)
PS2_ZERO: U1.17 (PC3), U3.5 (Q2)
SCK: D3.1 (K), U1.2 (PA2)
SI: D2.1 (K), U1.3 (PA1)
SO: U1.14 (PC0), U6.2 (SO)
~CS: J1.16, U1.6 (~CS)
~INT: J1.15, U4.5 (Q)
~RD: J1.17, U1.5 (~RD)
~RESET: J1.19, U5.1, U5.2
~SPI_CS: D4.1 (K), U1.1 (PA3)
~WR: J1.18, U1.36 (~WR)

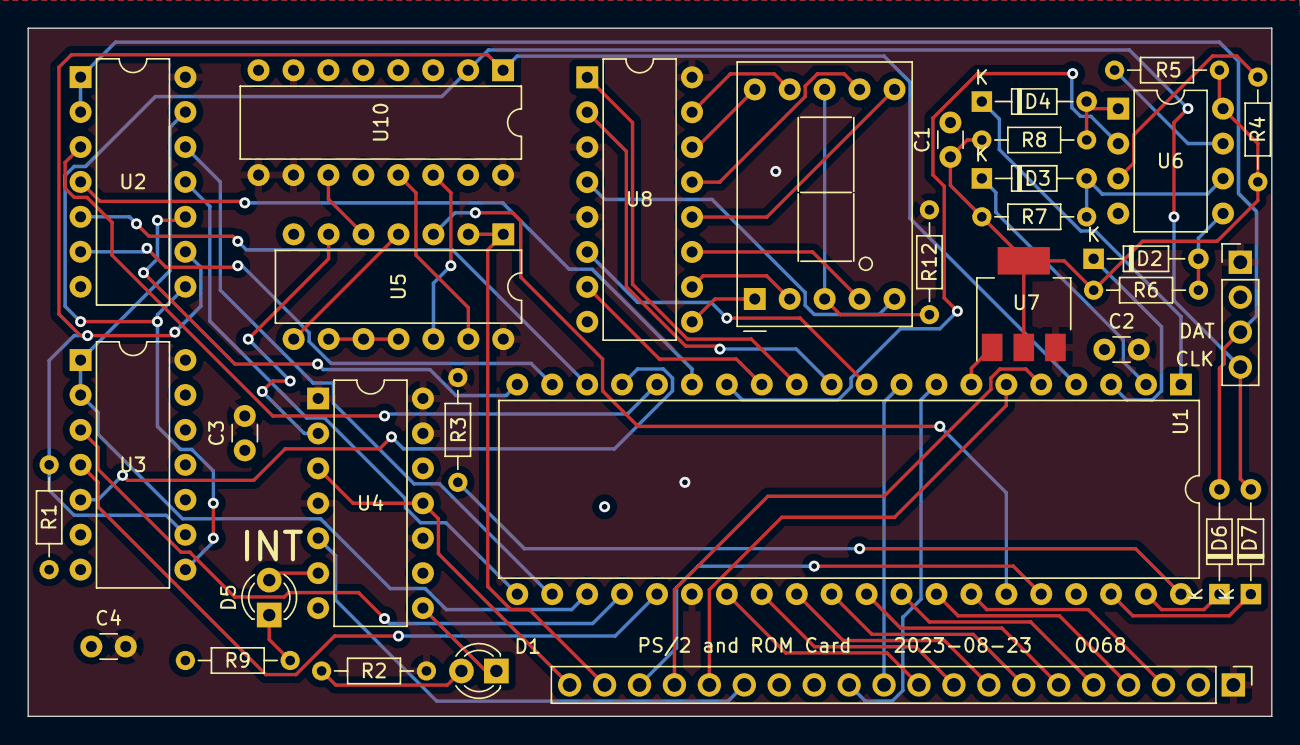
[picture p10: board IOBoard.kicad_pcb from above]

Board: 4 copper layers, 90.4 x 50.0 mm, 33 parts (0 on the bottom side), 69 nets.

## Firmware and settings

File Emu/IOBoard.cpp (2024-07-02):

#include <cstdint>
#include <cstdio>
#include <cstdlib>

#include "spiflash.h"
#include "IOBoard.h"
#include "cdp1855.h"
#include "6800.h"
#include "gpu.h"
#include "computer.h"

/*
 * "IOBoard" is a 82C55 interacting with a PS/2 keyboard interface implemented in 74-series logic
 * It also generates interrupts when a code is received from the keyboard
 * Secondly, there is a spiflash RAM, also connected to the 82C55 and a 7-segment BCD display which is not emulated here
 */

IOBoard::IOBoard(Computer& c) : comp(c) {
	reset();
}

void IOBoard::reset() {
	ctrl_word = 0b10011011;
	porta_setting = portb_setting = portc_setting = 0;
	porta_out = 0xFF;
	portb_in = 0;
	portc_in = 0;
	curr_sdi = 1;
	interrupt_latch = 0;
}

void IOBoard::step() {
	if(((ctrl_word >> 4) & 1) != 0) porta_out = 0xFF;
	else porta_out = porta_setting;
	if(((ctrl_word >> 3) & 1) != 0) bcd_val = 0xF;
	else bcd_val = portc_setting >> 4;
	led_state = (porta_out >> 4) & 1;
	
	curr_sdi = 1;
	if(((porta_out >> 3) & 1) != 0) flash.reset();
	else curr_sdi = flash.update((porta_out >> 2) & 1, (porta_out >> 1) & 1);
	portc_in &= 0xFE;
	portc_in |= curr_sdi;
	
	uint8_t shifter_reset = porta_out & 1;
	if(!shifter_reset) interrupt_latch = 0;
}

void IOBoard::write(uint8_t addr, uint8_t val) {
	addr &= 3;
	if(addr == 0) {
		//PORTA
		porta_setting = val;
	}else if(addr == 1) {
		//PORTB
		portb_setting = val;
	}else if(addr == 2) {
		//PORC
		portc_setting = val;
	}else if(addr == 3) {
		//Control
		if((val >> 7) != 0) {
			if(val != 0x83) printf("WARN: IO Board control word not 0x83, which will cause issues\r\n");
			ctrl_word = val;
		}else {
			uint8_t bit = (val >> 1) & 7;
			portc_setting &= ~(1 << bit);
			if((val & 1) != 0) portc_setting |= 1 << bit;
		}
	}
}

uint8_t IOBoard::read(uint8_t addr) {
	addr &= 3;
	if(addr == 0) {
		//PORTA
		if(((ctrl_word >> 4) & 1) != 0) return 0xFF;
		else return porta_setting;
	}else if(addr == 1) {
		//PORTB
		if(((ctrl_word >> 1) & 1) != 0) return portb_in;
		else return portb_setting;
	}else if(addr == 2) {
		//PORTC
		uint8_t res = 0;
		if(((ctrl_word >> 3) & 1) != 0) res |= 0xF0;
		else res |= portc_setting & 0xF0;
		if(((ctrl_word >> 0) & 1) != 0) res |= portc_in & 0x0F;
		else res |= portc_setting & 0x0F;
		return res;
	}
	return 0xFF;
}

uint8_t IOBoard::pending_interrupt() {
	return interrupt_latch;
}

unsigned char reverse(unsigned char b) {
   b = (b & 0xF0) >> 4 | (b & 0x0F) << 4;
   b = (b & 0xCC) >> 2 | (b & 0x33) << 2;
   b = (b & 0xAA) >> 1 | (b & 0x55) << 1;
   return b;
}

void IOBoard::set_ps2_val(uint8_t val) {
	interrupt_latch = 1;
	portb_in = reverse(val);
	portc_in &= 0b11110001;
	portc_in |= 4;
	uint8_t parity = 0;
	for(uint8_t i = 0; i < 8; i++) {
		parity = parity ^ ((val >> i) & 1);
	}
	if(!parity) portc_in |= 2;
}

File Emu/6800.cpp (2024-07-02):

#include <cstdint>
#include <cstdio>
#include <cstdlib>

#include "spiflash.h"
#include "IOBoard.h"
#include "cdp1855.h"
#include "6800.h"
#include "gpu.h"
#include "computer.h"

MC6800::MC6800(Computer& c) : comp(c) {
	//reset();
}

void MC6800::reset() {
	A = B = 0;
	SP = X = 0;
	SR = 128+64;
	PC = (comp.memory_read(0xFFFE) << 8) | comp.memory_read(0xFFFF);
	printf("Initial pc: %04x\r\n", PC);
	trace_on = 0;
}

#define FLAG_C 1
#define FLAG_V 2
#define FLAG_Z 4
#define FLAG_N 8
#define FLAG_I 16
#define FLAG_AC 32

void MC6800::set_conditions_for8(int8_t val) {
	SR &= ~(FLAG_Z | FLAG_N | FLAG_V);
	if(val == 0) SR |= FLAG_Z;
	if(val < 0) SR |= FLAG_N;
}

void MC6800::set_conditions_for16(int16_t val) {
	SR &= ~(FLAG_Z | FLAG_N | FLAG_V);
	if(val == 0) SR |= FLAG_Z;
	if(val < 0) SR |= FLAG_N;
}

void MC6800::branch() {
	int8_t disp = (int8_t)comp.memory_read(PC);
	PC += disp;
	PC++;
}

uint8_t MC6800::add(uint8_t a, uint8_t b, uint8_t carry_in) {
	uint16_t res = a + b + carry_in;
	int8_t val = (int8_t)res;
	SR &= ~(FLAG_Z | FLAG_N | FLAG_V | FLAG_C);
	set_conditions_for8(val);
	if(res > 255) SR |= FLAG_C;
	if((a >> 7) == (b >> 7) && ((res >> 7) & 1) != (b >> 7)) SR |= FLAG_V;
	return (uint8_t)res;
}

uint8_t MC6800::subtract(uint8_t a, uint8_t b, uint8_t borrow_in) {
	uint16_t res = a - b - borrow_in;
	int8_t val = (int8_t)res;
	SR &= ~(FLAG_Z | FLAG_N | FLAG_V | FLAG_C);
	set_conditions_for8(val);
	if(res > 255) SR |= FLAG_C;
	b = ~b;
	if((a >> 7) == (b >> 7) && ((res >> 7) & 1) != (b >> 7)) SR |= FLAG_V;
	return (uint8_t)res;
}

//C,Z,S,O,Ac,I
void MC6800::step() {
	uint8_t opcode = comp.memory_read(PC);
	if(trace_on) {
		printf("%02x @ %04x\r\n", opcode, PC);
	}
	PC++;
	if(opcode == 0x00) {
		//if(trace_on) exit(0);
		trace_on = !trace_on;
	}else if(opcode == 0x01) {
		//NOP
	}else if(opcode == 0x0F) {
		//SEI
		SR |= FLAG_I;
	}else if(opcode == 0x0E) {
		//CLI
		SR &= ~FLAG_I;
	}else if(opcode == 0x8E) {
		//LDS #data16
		SP = (comp.memory_read(PC) << 8) | comp.memory_read(PC + 1);
		PC += 2;
		printf("New SP: %04x\r\n", SP);
		SR &= ~(FLAG_Z | FLAG_N | FLAG_V);
		if(SP == 0) SR |= FLAG_Z;
		if((SP & 32768) != 0) SR |= FLAG_N;
	}else if(opcode == 0xAD || opcode == 0xBD) {
		uint16_t targ;
		if(opcode == 0xAD) {
			//JSR d8,X
			targ = X + comp.memory_read(PC);
			PC++;
		}else {
			//JSR a16
			targ = (comp.memory_read(PC) << 8) | comp.memory_read(PC + 1);
			PC += 2;
		}
		comp.memory_write(SP, PC & 0xFF);
		comp.memory_write(SP - 1, PC >> 8);
		SP -= 2;
		PC = targ;
	}else if(opcode == 0x86 || opcode == 0xC6) {
		//LDA A/B #
		uint8_t val = comp.memory_read(PC);
		PC++;
		set_conditions_for8(val);
		if(opcode == 0x86) A = val;
		else B = val;
	}else if(opcode == 0xB7 || opcode == 0xF7) {
		//STA A/B a16
		uint16_t addr = (comp.memory_read(PC) << 8) | comp.memory_read(PC + 1);
		PC += 2;
		comp.memory_write(addr, opcode == 0xB7 ? A : B);
		set_conditions_for8(opcode == 0xB7 ? A : B);
	}else if(opcode == 0x39) {
		//RTS
		PC = (comp.memory_read(SP + 1) << 8) | comp.memory_read(SP + 2);
		SP += 2;
	}else if(opcode == 0x36 || opcode == 0x37) {
		//PSH A/B
		comp.memory_write(SP, opcode == 0x36 ? A : B);
		SP--;
	}else if(opcode == 0x4A || opcode == 0x5A) {
		//DEC A/B
		uint8_t val = opcode == 0x4A ? A : B;
		set_conditions_for8(val - 1);
		if(val == 128) SR |= FLAG_V;
		if(opcode == 0x4A) A = val - 1;
		else B = val - 1;
	}else if(opcode == 0x26) {
		//BNE
		if((SR & FLAG_Z) == 0) branch();
		else PC++;
	}else if(opcode == 0x32 || opcode == 0x33) {
		//PUL A/B
		SP++;
		uint8_t val = comp.memory_read(SP);
		if(opcode == 0x32) A = val;
		else B = val;
	}else if(opcode == 0x4F || opcode == 0x5F) {
		//CLR A/B
		if(opcode == 0x4F) A = 0;
		else B = 0;
		SR &= ~(FLAG_C | FLAG_N | FLAG_V);
		SR |= FLAG_Z;
	}else if(opcode == 0x97 || opcode == 0xD7) {
		//STA A/B a8
		uint8_t addr = comp.memory_read(PC);
		PC++;
		uint8_t val = opcode == 0x97 ? A : B;
		comp.memory_write(addr, val);
		set_conditions_for8(val);
	}else if(opcode == 0x7E) {
		//JMP a16
		PC = (comp.memory_read(PC) << 8) | comp.memory_read(PC + 1);
	}else if(opcode == 0x6E) {
		//JMP d8,X
		uint8_t d = comp.memory_read(PC);
		PC = X + d;
	}else if(opcode == 0xB6 || opcode == 0xF6) {
		//LDA A/B a16
		uint16_t addr = (comp.memory_read(PC) << 8) | comp.memory_read(PC + 1);
		PC++; PC++;
		uint8_t val = comp.memory_read(addr);
		set_conditions_for8(val);
		if(opcode == 0xB6) A = val;
		else B = val;
	}else if(opcode == 0x31) {
		//INS
		SP++;
	}else if(opcode == 0x94 || opcode == 0xD4) {
		//AND A/B a8
		uint8_t addr = comp.memory_read(PC);
		PC++;
		uint8_t val = comp.memory_read(addr);
		val = val & (opcode == 0x94 ? A : B);
		set_conditions_for8(val);
		if(opcode == 0x94) A = val;
		else B = val;
	}else if(opcode == 0x27) {
		//BEQ
		if((SR & FLAG_Z) != 0) branch();
		else PC++;
	}else if(opcode == 0x84 || opcode == 0xC4) {
		//AND A/B #
		uint8_t val = comp.memory_read(PC);
		PC++;
		val = val & (opcode == 0x84 ? A : B);
		set_conditions_for8(val);
		if(opcode == 0x84) A = val;
		else B = val;
	}else if(opcode == 0xCE) {
		//LDX #
		uint16_t val = (comp.memory_read(PC) << 8) | comp.memory_read(PC + 1);
		PC++; PC++;
		X = val;
		set_conditions_for16(X);
	}else if(opcode == 0xA1 || opcode == 0xE1) {
		//CMP A/B d8,X
		uint8_t val = comp.memory_read(PC);
		PC++;
		val = comp.memory_read(X + val);
		subtract(opcode == 0xA1 ? A : B, val, 0);
	}else if(opcode == 0x11) {
		//CBA
		subtract(A, B, 0);
	}else if(opcode == 0x8B || opcode == 0xCB) {
		//ADD A/B #
		uint8_t val = comp.memory_read(PC);
		PC++;
		val = add(opcode == 0x8B ? A : B, val, 0);
		if(opcode == 0x8B) A = val;
		else B = val;
	}else if(opcode == 0x96 || opcode == 0xD6) {
		//LDA A/B a8
		uint8_t val = comp.memory_read(PC);
		PC++;
		val = comp.memory_read(val);
		set_conditions_for8(val);
		if(opcode == 0x96) A = val;
		else B = val;
	}else if(opcode == 0x89 || opcode == 0xC9) {
		//ADC A/B #
		uint8_t val = comp.memory_read(PC);
		PC++;
		val = add(opcode == 0x89 ? A : B, val, (SR & FLAG_C) != 0);
		if(opcode == 0x89) A = val;
		else B = val;
	}else if(opcode == 0x81 || opcode == 0xC1) {
		//CMP A/B #
		uint8_t val = comp.memory_read(PC);
		PC++;
		subtract(opcode == 0x81 ? A : B, val, 0);
	}else if(opcode == 0x0C) {
		//CLC
		SR &= ~FLAG_C;
	}else if(opcode == 0x46 || opcode == 0x56) {
		//ROR A/B
		uint8_t val = opcode == 0x46 ? A : B;
		uint8_t new_c = val & 1;
		val >>= 1;
		if((SR & FLAG_C) != 0) val |= 128;
		SR &= ~FLAG_C;
		set_conditions_for8(val);
		if(new_c) SR |= FLAG_C;
		if(opcode == 0x46) A = val;
		else B = val;
		if(((SR & FLAG_C) != 0 || (SR & FLAG_N) != 0) && !((SR & FLAG_C) != 0 && (SR & FLAG_N) != 0)) SR |= FLAG_V;
	}else if(opcode == 0x66 || opcode == 0x76) {
		uint16_t addr;
		if(opcode == 0x66) {
			//ROR d8,X
			uint8_t val = comp.memory_read(PC);
			PC++;
			addr = val + X;
		}else {
			//ROR a16
			addr = (comp.memory_read(PC) << 8) | comp.memory_read(PC + 1);
			PC += 2;
		}
		uint8_t val = comp.memory_read(addr);
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

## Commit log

2024-07-02 Initial commit.
    [ArithBoard.kicad_pcb, ArithBoard.kicad_sch, BaseBoard.kicad_pcb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]
2024-07-02 Fix menu software using incorrect flash base address on 6809.
    [menu.asm]
